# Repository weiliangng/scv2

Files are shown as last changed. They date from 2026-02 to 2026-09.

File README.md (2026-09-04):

# Technical documentation

- [SCV2 website source](website/README.md)
- [USB CLI setup and usage guide](CLI_GUIDE.md)
- [Downstream CAN telemetry receiver guide](CAN_TELEMETRY.md)
- [SCV2 technical documentation](https://merciful-iguanodon-c69.notion.site/RM8708A-Supercapacitor-controller-307fa7e594d880509271ff5a7605a5f0)

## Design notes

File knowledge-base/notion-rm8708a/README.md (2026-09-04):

# RM8708A Notion archive

This directory is a local, sanitized snapshot of the public Notion page
[`RM8708A Supercapacitor controller`](https://merciful-iguanodon-c69.notion.site/RM8708A-Supercapacitor-controller-307fa7e594d880509271ff5a7605a5f0).

- [`page.md`](page.md) preserves the page content in reading order.
- [`manifest.json`](manifest.json) records source identifiers, file sizes, and SHA-256 checksums.
- [`assets/`](assets/) contains the six embedded images, the social preview, the published firmware attachment, and two externally embedded TI PDFs.

The snapshot was captured from the anonymously accessible public-page API on
2026-09-04. Temporary Notion signed URLs, workspace permissions, user IDs, and
other unrelated internal metadata are intentionally not retained.

The page also links to project files that already live at the repository root:

- [`3D_4loko_2026-02-15.step`](../../3D_4loko_2026-02-15.step)
- [`ProPrj_supercap v0.1_2026-02-15.epro`](../../ProPrj_supercap%20v0.1_2026-02-15.epro)
- [`Calibration Script.ipynb`](../../Calibration%20Script.ipynb)

`assets/test.elf` is an untrusted binary snapshot. It has been archived but was
not executed.

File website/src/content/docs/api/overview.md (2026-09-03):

---
title: Interfaces overview
description: Choose and configure the referee UART, CAN, telemetry UART, and USB interfaces.
sidebar:
  order: 1
---

SCV2 separates robot control, fast telemetry, and bench diagnostics across four interfaces.

## Connections

| Interface | Configuration | Direction | Primary use |
|---|---|---|---|
| Referee UART | USART3, 115200, 8-N-1 | Receive | Referee power limit and buffer energy |
| CAN | Classic CAN, 1 Mbit/s | Bidirectional | Robot commands and fast telemetry |
| Telemetry UART | USART1 TX on PA9, 921600, 8-N-1 | Transmit | `T1` CSV record approximately every 10 ms |
| USB | CDC virtual COM port | Bidirectional | Interactive CLI and optional `T1` telemetry mirror |

## External control-source selection

External mode resolves the active command source in this order:

1. A fresh referee UART command
2. A fresh CAN command
3. No-source state when neither input is fresh

Command acceptance does not override protection. Faults, undervoltage lockout, capacitor-voltage lockout, direction rules, and switching timers may keep the power stage disabled.

## Choose an interface

### Robot integration

Use **CAN** for robot commands and the 1 kHz fast telemetry frame. Use **referee UART** when SCV2 should receive referee power and energy directly.

### Continuous diagnostics

Use **USART1 telemetry** for an always-on 69-field `T1` stream without sharing the USB port. Connect a 3.3 V receiver to PA9 at 921600 baud.

### Bench and pit work

Use **USB CDC** for the interactive CLI. USB can also mirror `T1` telemetry, but only one host application can normally own the COM port at a time.

## Next steps

- Decode the fast frame: [CAN telemetry](../can-telemetry/)
- Operate the diagnostic console: [USB CLI](../usb-cli/)
- Connect the dashboard: [Telemetry transports](../telemetry/)

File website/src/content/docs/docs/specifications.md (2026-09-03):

---
title: Technical specifications
description: Electrical limits, control modes, performance, and protection behavior.
sidebar:
  order: 1
---

## Electrical limits

| Port | Parameter | Range or limit |
|---|---|---|
| **IN — chassis bus** | Voltage | 12–28 V |
| | Current limit | −10 to +10 A; programmable in debug mode |
| | Power setting | −240 to +240 W in 1 W steps |
| | Reverse-flow voltage limit | 26.2 V if the battery disconnects or shuts down while reverse power is set |
| **OUT — supercapacitor** | Voltage and setting | 5–30 V; digitally programmable |
| | Current limit | −15 to +15 A; fixed limits |
| **Response** | Chassis load-step settling | <1 ms; 150 μs typical |
| **Performance** | Peak efficiency | Up to 97% |
| **Energy** | Supported bank | Up to 2,000 J stored |
| | Expected usable energy | Approximately 1,200–1,400 J |

## Sign convention

- **Positive power** flows from IN to OUT and charges the supercapacitor bank.
- **Negative power** flows from OUT to IN and supports the chassis bus.

The current and power limits apply to magnitude and direction. Read negative telemetry values using this convention rather than treating them as faults.

## Regulation

SCV2 supports:

- Constant input-power regulation
- Constant-current / constant-voltage charging
- Digitally programmable capacitor voltage
- External control using referee UART or CAN
- Manual and measurement modes for commissioning
- Guarded direct mode for expert bench work

## Protection and fault handling

The hardware provides:

- Short-circuit current limiting
- Overvoltage detection and shutdown on both ports
- IN-port undervoltage lockout
- Latched overvoltage status reporting
- Capacitor degradation detection
- Charge-voltage foldback when added energy does not produce the expected voltage rise
- Prevention of unintended backfeeding or “zombie power”

:::caution
The hardware is designed to tolerate hot-plugging the source and a charged or discharged capacitor bank, but these are not recommended operating procedures.
:::

## Related reference

- [Operating envelope](../operating-envelope/)
- [Interfaces overview](../../api/overview/)
- [CAN telemetry status bits](../../api/can-telemetry/#status-byte)

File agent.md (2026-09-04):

# SCV2 USB CLI, control, and telemetry guide

This document is the operating reference for agents and bench users working with the SCV2 firmware. The command implementation in `Core/Src/usb_cli.c`, the resolver in `Core/Src/scap_io_owner.c`, and constants in `Core/Inc/app_constants.h` are the source of truth. Check those files before extending this guide or relying on a remembered behavior.

## Agent operating rules

- Start with read-only observation: connect the USB CDC port, run `help`, disable the USB telemetry mirror if it obscures the prompt, and run `status`.
- Infer command effects by tracing the CLI handler through its mailbox or HAL call and then through `ScapIo_Resolve1kHz()` and the ADC ISR. An `ok` response only means the command was accepted; verify the requested state with `status` or `T1`, and verify the physical result with `swen_out`, GPIO measurement, or appropriate bench equipment.
- Do not guess the COM port, safe supply/load conditions, calibration values, GPIO target, DAC value, or acceptable power setpoint. If the requested hardware operation or its safe value is not explicit and cannot be established from the repository and fixture description, ask the user before issuing a mutating command.
- Treat `ctrl direct`, `gpio`, `dac`, `cal set`, `cal load`, and `cal save` as hardware-mutating operations. Use a current-limited, known-safe bench setup and arrange a shutdown path before using them.
- When this document and firmware disagree, document the observed mismatch and follow the current source. Do not silently preserve an obsolete test expectation.

## USB CLI quick start

The CLI is exposed as the board's USB CDC virtual COM port. Repository tooling conventionally opens it at 115200 baud, 8-N-1; USB CDC does not use that setting as a physical UART baud rate. The separate USART1 telemetry output is 921600 baud, 8-N-1 and is not the CLI.

1. Connect the board's USB device port and identify its virtual COM port. Do not assume the example `COM8` is correct for the current host.
2. Open the port in a serial terminal. Either CR or LF submits a command.
3. Wait for `CLI ready. Type 'help'.` and the `scv2> ` prompt. Press Enter once if the board was already running before the terminal connected.
4. Run `telemetry off` for a clean interactive prompt, then run `help` and `status`.

`status` deliberately averages 1000 samples with a 1 ms delay, so expect it to take about one second. It does not write control state, but command freshness and physical conditions can change while it is sampling. `telemetry on` interleaves `T1` records with ordinary CLI output on the same USB stream; the USART1 `T1` stream remains on regardless of this setting.

## CLI command reference

| Command | What it does | Important constraints |
|---|---|---|
| `help` | Prints the supported command syntax. | `dir` and `mode` are dispatched but intentionally absent because they are unavailable. |
| `status` | Reports control decision, physical pins, safety state, averaged electrical values, command mailboxes, telemetry/link statistics, DAC values, and ISR timing. | Read-only, but takes about one second. The displayed "Current mode" is the resolver decision, not merely the requested `ctrl` mode. |
| `telemetry on\|off\|toggle` | Controls the lossy USB mirror of `T1`. | Does not change the always-on USART1 stream or control behavior. |
| `ctrl external` | Selects external control. | Fresh UART power **and** energy win over fresh CAN; otherwise fresh CAN is used; otherwise the decision is `no-source`. |
| `ctrl manual` | Selects manual algorithm control. | Uses the last `pset`, or 50 W if none has been published. Manual SWEN is selected by timestamp against the pushbutton mailbox. |
| `ctrl measure` | Selects measurement mode. | Forces the requested SWEN output off without waiting for the minimum-on timer. |
| `ctrl direct` | Relinquishes normal MODE, DIR, SWEN, LED, and DAC1 algorithm updates so they can be driven directly. | Fault/watchdog and UVLO handling still take priority. Enter only on a safe bench. |
| `pset <-240..240>` | Publishes a persistent manual power mailbox in watts. | It affects power only in manual mode; it does not switch modes or enable SWEN. |
| `swen <0\|1>` | Publishes a persistent manual SWEN mailbox. | It affects output selection only in manual mode. The newer pushbutton/manual mailbox wins, and safety still overrides it. |
| `gpio write <PIN> <0\|1>` | Writes a GPIO output. | The parser accepts optional `P`, ports compiled for the MCU, and pins `0..15`, case-insensitively; it is not an allowlist of safe outputs. |
| `gpio toggle <PIN>` | Toggles a GPIO output. | Same parser and hazards as `gpio write`. |
| `dac set <1\|3> <1\|2> <0..4095>` | Writes a raw 12-bit DAC value. | DAC1 requires `ctrl direct`; DAC3 does not. Values are volatile unless represented by saved boot calibration. |
| `cal set <NAME> <VALUE>` | Changes an active calibration constant in RAM. | Does not persist until `cal save`; the two DAC3 boot values are also applied to hardware immediately. |
| `cal load` | Loads the saved calibration set from emulated EEPROM and applies the saved DAC3 boot values. | Returns an error if no valid saved set exists and replaces unsaved RAM changes. |
| `cal save` | Saves the complete active calibration set to emulated EEPROM. | Persistent hardware mutation; verify values before saving. |
| `dir ...` / `mode ...` | Returns `unavailable: main mode control is staged off`. | Use guarded GPIO commands in direct mode instead. |

Power-stage GPIO writes and toggles for PB1/DIR, PB4/SWEN, PB5/MODEMSB, PB6/MODELSB, and PA10/LED are rejected unless the requested mode is direct. Other syntactically valid pins are not protected by this check; writing a peripheral-owned, input-only, or otherwise unsafe pin can still disrupt the board.

Calibration names are `A_VBUS`, `B_VBUS`, `A_ILOAD`, `B_ILOAD`, `MIDPOINT`, `A_INP`, `B_INP`, `A_INN`, `B_INN`, `A_VCAP`, `B_VCAP`, `A_OP`, `B_OP`, `A_ON`, `B_ON`, `DAC3_CH1_BOOT_U12`, and `DAC3_CH2_BOOT_U12`. Float inputs must be finite; `A_VBUS` must also be nonzero, and DAC boot values must be `0..4095`.

## Safe command workflows

### Observe without changing control

```text
telemetry off
status
```

Use `telemetry on` only when a consumer is ready to separate complete `T1` lines from the prompt and command responses.

### Manual power and SWEN

```text
swen 0
pset 80
ctrl manual
status
swen 1
status
swen 0
ctrl external
status
```

Set `swen 0` and confirm the physical SWEN pin before enabling the power stage. The `pset` and manual `swen` mailboxes persist until reset or replacement. A mode or resolver-decision transition publishes pushbutton SWEN off; after entering manual mode, the newest manual `swen` or physical pushbutton event determines the request.

### Direct GPIO or DAC1 work

```text
ctrl direct
gpio write PB4 0
# perform only the explicitly planned GPIO/DAC operations
gpio write PB4 0
ctrl external
status
```

Direct mode leaves the current stage outputs in their applied state; entering it does not automatically clear every pin. Before leaving, explicitly put altered outputs into the intended safe state. Fault/watchdog handling can still force SWEN off, and UVLO can still update DIR/DAC1 while holding SWEN off.

### Calibration

At the start of a calibration session, before making unsaved changes, record `status` and the values printed by a successful `cal load`. Use `cal set` for one value at a time, validate the measurements, and run `cal save` only after the complete active set is known-good. There is no read-only CLI command that prints the active calibration set: `cal load` replaces RAM values and applies the saved DAC3 boot outputs, so never use it merely to inspect values that must not be changed.

## Control behavior inferred from `scap_io_owner.c`

The 1 kHz resolver publishes a double-buffered fast command, and the ADC ISR applies the physical DIR, DAC1, SWEN, and LED behavior. The priority and source flow are:

1. A watchdog failure or latched Vbus/Vcap over-voltage fault forces SWEN off immediately. A fault clears only after 500 consecutive safe 1 kHz resolver cycles and a subsequent fault-free fast update.
2. Vbus UVLO enters at `<=10 V`, exits at `>=11 V`, and forces SWEN off.
3. Direct mode leaves normal power-stage output ownership to direct writes; measure mode forces SWEN off; manual mode uses manual inputs; external mode selects fresh UART power+energy before fresh CAN.
4. CAN and UART fields are fresh for 300 ms. No fresh external source produces `no-source`, zero power, and a false SWEN policy request.
5. Outside direct, measure, fault, and UVLO handling, SWEN observes a 50 ms minimum-on time and a 1 ms minimum-off time.

For enabled external commands with valid energy, SWEN permission is based on converter direction and Vcap lockout, not on crossing an energy threshold. The initial runtime maximum is 26.3 V. Charging is allowed only while `i_conv > 0` and Vcap is below that maximum; it resumes at 0.1 V below the current maximum. The discharge lockout is 20% of the current maximum and resumes 0.1 V above that level. Initially these thresholds are 26.3/26.2 V for charge and 5.26/5.36 V for discharge. A zero converter-current command allows neither direction.

Energy changes the resolved power setpoint while a direction is allowed:

| Direction | Energy condition | Resolved power adjustment |
|---|---|---:|
| Charge | `energy > 50 J` | `command power + 10 W` |
| Charge | `energy <= 50 J` | `command power - 20 W` |
| Discharge | `energy < 20 J` | `command power - 10 W` |
| Discharge | `energy >= 20 J` | `command power + 20 W` |

CAN energy `777` is the disabled sentinel: it bypasses both the direction/Vcap energy-policy permission and the power adjustment, but it does not bypass command freshness, the CAN SWEN bit, fault/watchdog handling, UVLO, or minimum-on/off timing.

Outside direct mode the resolver writes MODE[1:0] to `01`, the normal algorithm mode. Use `swen_req` to see the selected source's request, `decision` to see which control branch won, `pset_W` to see the adjusted power, and `swen_out` to verify what the hardware actually received.

## Telemetry `T1` decoder

USART1 emits one CSV record every 10 ms from boot at 921600 baud, 8-N-1. The USB CLI command `telemetry on|off|toggle` controls an independent USB CDC mirror of the same records; it does not affect USART1 or control. Every record starts with `T1`; remaining columns are positional and must be decoded in the order below. It is a best-effort snapshot, so DMA, register, and shared-state values can be up to one control cycle apart.

### Conventions

- **Binary** is `0` or `1`.
- **Continuous** is a decimal integer in the stated unit.
- **N-ary** is a decimal enum defined below.
- Raw ADC and DAC values are unsigned 12-bit counts (`0..4095`).
- `valid` means a mailbox has published an accepted value. `fresh` means it is within the shared 300 ms command timeout for CAN and UART.

### Columns

| # | Field | Type / range | Meaning and source |
|---:|---|---|---|
| 1 | `seq` | continuous, uint32 | T1 telemetry record sequence shared by USART1 and USB. |
| 2 | `adc_hz` | continuous, Hz | Measured ADC1 DMA sequence rate. |
| 3 | `usb_drop` | continuous, uint32 | Cumulative records rejected by the lossy USB telemetry queue. |
| 4 | `dma_last` | continuous, cycles | Last ADC1 DMA ISR execution time. |
| 5 | `dma_max` | continuous, cycles | Maximum ADC1 DMA ISR execution time since boot. |
| 6 | `adc_vcap` | continuous, 0..4095 | ADC1 rank 1 raw Vcap input: PA0 / ADC1_IN1. |
| 7 | `adc_vbus` | continuous, 0..4095 | ADC1 rank 2 raw Vbus input: PA1 / ADC1_IN2. |
| 8 | `adc_iload` | continuous, 0..4095 | ADC2 rank 1 differential Iload sample: PA6/PA7. |
| 9 | `adc_iop` | continuous, 0..4095 | ADC2 rank 2 IMONOP sample via OPAMP2: PB14. |
| 10 | `adc_ion` | continuous, 0..4095 | ADC2 rank 3 IMONON sample via OPAMP3: PB13. |
| 11 | `vc_mV` | continuous, signed mV | `adc_vcap` after active Vcap calibration. |
| 12 | `vb_mV` | continuous, signed mV | `adc_vbus` after active Vbus calibration. |
| 13 | `il_mA` | continuous, signed mA | `adc_iload` after active Iload calibration. |
| 14 | `iop_mA` | continuous, signed mA | `adc_iop` after active IMONOP calibration. |
| 15 | `ion_mA` | continuous, signed mA | `adc_ion` after active IMONON calibration. |
| 16 | `io_mA` | continuous, signed mA | Selected output current: larger of IMONOP and negative IMONON. |
| 17 | `ic_mA` | continuous, signed mA | Calculated converter-current command, clamped to ±10 A. |
| 18 | `pset_W` | continuous, signed W | Power setpoint selected by the control resolver. |
| 19 | `btn_in` | binary | Physical PC13 pushbutton level; control uses its debounced rising edge. |
| 20 | `dir_out` | binary | Physical PB1 direction output; `1` is positive converter-current direction. |
| 21 | `swen_out` | binary | Physical PB4 switch-enable after safety, direction/Vcap policy, and min-on/off gating. |
| 22 | `mode_out` | n-ary, 0..3 | Physical PB5:PB6 mode bits (`2*MODEMSB + MODELSB`); normal algorithm mode is `1`. |
| 23 | `rvsoff_out` | binary | Physical PB3 reverse-switch-off output. |
| 24 | `nsil_out` | binary | Physical PB7 NSIL output. |
| 25 | `led_out` | binary | Physical PA10 status LED output. |
| 26 | `dac1_ch1` | continuous, 0..4095 | Live DAC1 channel 1, IMONINP comparator/reference output. |
| 27 | `dac1_ch2` | continuous, 0..4095 | Live DAC1 channel 2, IMONINN comparator/reference output. |
| 28 | `dac3_ch1` | continuous, 0..4095 | Live DAC3 channel 1, OPAMP1 feedback/reference output. |
| 29 | `dac3_ch2` | continuous, 0..4095 | Live DAC3 channel 2, COMP4 reference output. |
| 30 | `mode_req` | n-ary, 0..3 | Requested mode: `0=external`, `1=manual`, `2=measure`, `3=direct GPIO`. |
| 31 | `decision` | n-ary, 0..7 | Resolver result: `0=fault disable`, `1=idle/UVLO`, `2=no source`, `3=manual algorithm`, `4=CAN algorithm`, `5=UART algorithm`, `6=measure`, `7=direct GPIO`. |
| 32 | `swen_req` | binary | Resolver request before final output gating. |
| 33 | `safe` | binary | Current ADC safety check has no Vbus/Vcap over-voltage fault. |
| 34 | `uvlo` | binary | Undervoltage lockout; enters at Vbus ≤10 V, exits at Vbus ≥11 V. |
| 35 | `fault_latched` | binary | Over-voltage fault is latched and forces SWEN off until recovery. |
| 36 | `fault_bits` | bitmask, 0..3 | `bit0=Vbus ≥30 V`; `bit1=Vcap ≥30 V`. |
| 37 | `fault_healthy_ms` | continuous, 0..500 | Consecutive safe time while clearing a latched fault. |
| 38 | `can_bus` | binary | Any CAN FIFO1 traffic observed in the last 200 ms. |
| 39 | `can_p` | continuous, W 50..120 when valid | CAN command power. |
| 40 | `can_p_valid` | binary | Valid CAN command packet accepted since boot. |
| 41 | `can_p_fresh` | binary | CAN command is no more than 300 ms old. |
| 42 | `can_e` | continuous, J 0..60 or 777 | CAN energy used for power adjustment; `777` disables the energy/Vcap policy. |
| 43 | `can_e_valid` | binary | Accepted CAN energy is usable: packet valid and `can_e != 777`. |
| 44 | `can_e_fresh` | binary | CAN energy packet freshness, shared with CAN power. |
| 45 | `can_e_disabled` | binary | CAN energy is the `777` disabled sentinel. |
| 46 | `can_swen` | binary | SWEN request carried by the CAN packet. |
| 47 | `can_swen_valid` | binary | Valid CAN command packet accepted since boot. |
| 48 | `can_swen_fresh` | binary | CAN SWEN packet freshness, shared with CAN power. |
| 49 | `uart_p` | continuous, W 50..120 when valid | Referee UART chassis power limit. |
| 50 | `uart_p_valid` | binary | CRC-validated referee power frame parsed since boot. |
| 51 | `uart_p_fresh` | binary | UART power is no more than 300 ms old. |
| 52 | `uart_e` | continuous, J 0..60 when valid | Referee UART buffer energy. |
| 53 | `uart_e_valid` | binary | CRC-validated referee energy frame parsed since boot. |
| 54 | `uart_e_fresh` | binary | UART energy is no more than 300 ms old. |
| 55 | `uart_swen_req` | binary | Derived request: `1` only while UART power and energy are both fresh. |
| 56 | `man_p` | continuous, signed W -240..240 when valid | Manual CLI power mailbox; it does not expire. |
| 57 | `man_p_valid` | binary | Manual power has been set by the CLI since boot. |
| 58 | `man_swen` | binary | Manual CLI SWEN mailbox request; it does not expire. |
| 59 | `man_swen_valid` | binary | Manual SWEN has been set by the CLI since boot. |
| 60 | `btn_swen` | binary | Debounced pushbutton SWEN mailbox request; it does not expire. |
| 61 | `btn_swen_valid` | binary | Pushbutton SWEN mailbox set since boot or reset by a mode transition. |
| 62 | `cap_energy_mJ` | continuous, signed mJ | Integrated capacitor energy; charging adds and discharging subtracts. |
| 63 | `vcap_max_mV` | continuous, mV | Current runtime Vcap maximum used by charge lockout, discharge lockout, and CAN capacity scaling. |
| 64 | `cap_unhealthy` | binary | Latched once three consecutive bad one-minute capacitor-health windows cause a derate. |
| 65 | `cap_bad_windows` | continuous, 0..3 | Current consecutive bad-window count; reset after a derate or a good window. |
| 66 | `cap_derates` | continuous, uint8 | Number of 0.1 V runtime derates since boot. |
| 67 | `cap_dE_mJ_min` | continuous, signed mJ/min | Integrated energy change measured over the last completed one-minute health window. |
| 68 | `cap_dV_mV_min` | continuous, signed mV/min | Vcap trend from averaged endpoints of the last completed one-minute health window. |
| 69 | `can_tx_enqueue_fail` | continuous, uint32 | Cumulative `HAL_FDCAN_AddMessageToTxFifoQ()` failures since boot; this does not report missing acknowledgements or arbitration delays. |

`cap_energy_mJ` starts at zero. The 50 kHz ADC ISR integrates signed `Vcap * Iout` energy into 50-sample (1 ms) blocks; the 1 kHz task transfers completed blocks into the signed run-long counter while retaining fractional mJ. `Iout` is forced to zero while SWEN is off. On each upward crossing of 23.0 V the counter is rebased to 1,322,500 mJ, the ideal stored energy of a 5 F capacitor at 23.0 V. The anchor re-arms after Vcap falls to 22.9 V or below.

The capacitor-health check compares energy and voltage across non-overlapping one-minute windows. Its voltage trend compares the average Vcap from the first 10 seconds with the average from the last 10 seconds, normalized to mV/min; raw Vcap remains in use for the 23 V anchor and control thresholds. A window is bad when energy rises by at least 500,000 mJ while the averaged Vcap trend is less than 100 mV/min. Three consecutive bad windows latch `cap_unhealthy`, reduce the runtime Vcap maximum by 0.1 V, and restart the count. Repeated groups of three bad windows continue derating down to a 23.0 V floor. The maximum, latch, and counters reset on reboot; the fixed 30 V hardware-safety threshold is unchanged.

### Control precedence

In external mode, fresh UART power plus energy wins; otherwise fresh CAN is used; otherwise the controller has no source. In manual mode, the newer pushbutton or manual-SWEN mailbox wins. Faults and UVLO override normal operation. Valid external energy adjusts `pset_W`; converter direction and Vcap lockout determine whether that source may enable SWEN. Use `swen_out` to verify what hardware actually received.

### External dashboard

The dashboard is maintained and released independently in
[`weiliangng/scv2-dashboard`](https://github.com/weiliangng/scv2-dashboard).
That repository owns the desktop source, dependencies, Windows packaging,
usage documentation, CI, and dashboard releases. This firmware repository owns
the `T1` producer and its field semantics; coordinate changes to the number,
order, units, or meaning of `T1` fields with the dashboard repository.

The firmware provides an optional USB CDC `T1` mirror controlled by the
`telemetry on`, `telemetry off`, and `telemetry toggle` CLI commands. It also
provides the always-on USART1 TX telemetry stream at 921600 baud. Dashboard
connection handling and bridge network configuration are documented in their
respective repositories. CLI commands can mutate hardware, so use the same
safe-bench constraints as a serial terminal.

### Firmware releases

To publish firmware, push an annotated tag matching `firmware-v*`, for example
`firmware-v1.0.0`. `.github/workflows/firmware-release.yml` builds MinSizeRel
firmware on Linux with pinned Arm GNU Toolchain 14.3.Rel1 and publishes only
`SCV2_Firmware.elf`, `.bin`, `.hex`, `.map`, build metadata, and firmware
checksums. `SCV2_Firmware.elf` is the file for STM32CubeProgrammer.

To verify that a release ELF matches a local build, run:

```powershell
Get-FileHash -LiteralPath .\build\MinSizeRel\test.elf -Algorithm SHA256
```

Compare it with `SCV2_Firmware.sha256` from the release. Equal SHA-256 values
mean the two ELF files are byte-for-byte identical. The release's
`SCV2_Firmware.build.txt` records the compiler and build-tool versions to
diagnose a mismatch.

## CAN five-byte command test guide

This is an automation-ready bench-test matrix for commands sent by the DEVC/peer device to this board. It covers protocol and control-behaviour equivalence classes and validation boundaries; it is intentionally not a brute-force test of all `2^40` possible payloads.

### Test-rig correlation and safe profiles

- The sender STM32 writes `CASE <id>` to its USB CDC port immediately before it transmits the listed CAN frame. The host records that event and SCV2's `T1` stream with one monotonic PC clock; it never tries to correlate by the ignored `reset` byte.
- Enable `telemetry on` on SCV2. A normal target observation is the first complete `T1` record after a case event, within 30 ms. FIFO1-only traffic is polled at 100 ms, so its `can_bus=1` observation has a 130 ms deadline. `T1` itself is sampled every 10 ms.
- Profile `S` means `mode_req=0`, both UART freshness fields are `0`, `safe=1`, `uvlo=0`, `fault_latched=0`, and no earlier energy/Vcap lockout is retained. Use a current-limited supply and a safe load; start with `enable_module=0` cases.
- Baseline `B0` is the accepted frame `[00 00 55 0A 00]`: power 85 W, energy 10 J, SWEN off. For a rejection test, send B0, wait at least 310 ms, then send the candidate. Immediately before the candidate, the expected retained state is `can_p=85`, `can_p_valid=1`, `can_p_fresh=0`, `can_e=10`, `can_e_valid=1`, `can_e_fresh=0`, `can_e_disabled=0`, `can_swen=0`, `can_swen_valid=1`, `can_swen_fresh=0`, `can_bus=0`, `decision=2`, `pset_W=0`, `swen_req=0`, and `swen_out=0`.
- `valid` means a command was accepted since boot; it does **not** expire. All three CAN `fresh` fields use the same accepted-command timestamp and become `0` only after more than 300 ms without another accepted command.
- Do not assert exact `seq`, ADC/DAC counts, measured voltages/currents, `dir_out`, or `led_out` unless the fixture controls their inputs. `swen_out` is exact only when the stated analogue/safety profile and its 1 ms/50 ms timing history make it deterministic.

### Wire contract

Send a Classic CAN **standard data frame** with 11-bit ID `0x067` and DLC `5`.

| Byte | Name | Encoding | Accepted values | Effect |
|---:|---|---|---|---|
| 0 | `enable_module` | unsigned byte | `0` or `1` | Publishes CAN SWEN request: `0=off`, `1=on`. |
| 1 | `reset` | unsigned byte | any `0..255` | Currently ignored; it does not reset faults, timers, or the mailbox. |
| 2 | `pow_limit` | unsigned byte, W | `50..120` | Sets the CAN power setpoint. |
| 3 | `energy_buffer` LSB | unsigned byte | see below | Low byte of the little-endian energy value. |
| 4 | `energy_buffer` MSB | unsigned byte | see below | High byte of the little-endian energy value. |

`energy_buffer = byte[3] + 256 * byte[4]`. It is valid when `0..60 J`, or when it is exactly `777` (`0x0309`, bytes `09 03`). `777` is the disabled-energy sentinel: it bypasses direction/Vcap permission and power adjustment but does not bypass freshness, the CAN SWEN bit, UVLO, fault handling, or the SWEN timing limiter.

For sender notation below, payloads are hexadecimal bytes in the order on the wire: `[enable reset power energy_LSB energy_MSB]`.

For every accepted packet with values `(P,E,SW)`, the common `T1` assertion within 30 ms is: `can_bus=1`, `can_p=P`, `can_p_valid=1`, `can_p_fresh=1`, `can_e=E`, `can_e_fresh=1`, `can_e_disabled=(E==777)`, `can_e_valid=(E!=777)`, `can_swen=SW`, `can_swen_valid=1`, and `can_swen_fresh=1`. Under profile `S`, it additionally gives `mode_req=0`, `decision=4`, and `swen_req=SW`. `pset_W=P` when `SW=0`, when `E=777`, or while no direction is allowed; an enabled valid-energy command uses the direction-dependent adjustment table above. The per-case cells below state the remaining exact or conditional output assertions.

### Transport and frame-shape tests

| Case | Frame sent and precondition | Expected observed `T1` values |
|---|---|---|
| T1 baseline | `S`; standard data ID `0x067`, DLC 5, `[00 00 50 00 00]` | Common accepted assertion `(50,0,0)`; also `swen_out=0`. |
| T2 wrong standard ID | `B0`; standard data ID `0x066`, DLC 5, `[00 00 50 00 00]` | Within 130 ms, `can_bus=1`. All B0 mailbox values remain retained and stale: `can_p=85`, `can_e=10`, `can_swen=0`, all CAN `valid=1`, all CAN `fresh=0`; in `S`, `decision=2`, `pset_W=0`, `swen_req=0`, `swen_out=0`. |
| T3 extended ID | `B0`; extended data ID `0x67`, DLC 5, `[00 00 50 00 00]` | Same T1 assertion as T2. The global non-matching extended filter sends this to FIFO1, not the command callback. |
| T4 remote frame | `B0`; standard remote ID `0x067`, DLC 5 | Through 210 ms, `can_bus=0` and every B0 field remains unchanged/stale. Remote frames are rejected by the global filter, so they do not enter FIFO0/FIFO1. |
| T5 wrong DLC | `B0`; standard data ID `0x067`, DLC `0..4` or `6..8` | Within 30 ms, `can_bus=1`; every B0 mailbox field remains unchanged/stale. This proves activity is noted before the DLC-5 check, but timestamp publication is not performed. |
| T6 FIFO drain/order | `S`; enqueue in order valid `[00 00 50 00 00]`, invalid `[02 00 50 00 00]`, valid `[01 FF 78 09 03]` | Within 30 ms of the queue becoming non-empty, common accepted assertion `(120,777,1)`, `decision=4`, `pset_W=120`, `swen_req=1`. With the switch known off for at least 1 ms, `swen_out=1`; `reset=FF` causes no separate effect. |

### Payload validation matrix

Every rejected payload uses stale B0. Therefore `can_p=85`, `can_e=10`, `can_swen=0`, all CAN `valid=1`, all CAN `fresh=0`, `decision=2`, `pset_W=0`, `swen_req=0`, and `swen_out=0` must remain true; because the ID/type/DLC are correct, `can_bus=1` must appear within 30 ms. This both proves mailbox preservation and proves that the rejected frame did not refresh B0's timestamp.

| Case | Payload and precondition | Expected observed `T1` values |
|---|---|---|
| P1 enable off | `S`; `[00 00 50 00 00]` | Common accepted assertion `(80,0,0)`; exact `swen_out=0`. |
| P2 enable on | `S`; `[01 00 50 00 00]` | Common accepted assertion `(80,0,1)` and `swen_req=1`. With an allowed charge direction, `pset_W=60` and SWEN may turn on; with an allowed discharge direction, `pset_W=70` and SWEN may turn on. With zero current direction or the relevant Vcap lockout, `pset_W=80` and `swen_out=0`. |
| P3 invalid enable | stale `B0`; `[02 00 50 00 00]`, then `[FF 00 50 00 00]` | Rejected assertion above for both frames. Values `2..255` form one invalid class. |
| P4 ignored reset | `S`; `[00 00 50 00 00]`, `[00 01 50 00 00]`, `[00 FF 50 00 00]` | After each frame, common accepted assertion `(80,0,0)` and `swen_out=0`. No T1 field distinguishes the three reset-byte values; no fault, UVLO, timing, or mailbox reset occurs. |
| P5 power below range | stale `B0`; `[00 00 00 00 00]`, `[00 00 31 00 00]` | Rejected assertion above for `0 W` and `49 W`. |
| P6 power lower boundary | `S`; `[00 00 32 00 00]` | Common accepted assertion `(50,0,0)`; `decision=4`, `pset_W=50`, `swen_out=0`. |
| P7 representative power | `S`; `[00 00 55 00 00]` | Common accepted assertion `(85,0,0)`; `decision=4`, `pset_W=85`, `swen_out=0`. |
| P8 power upper boundary | `S`; `[00 00 78 00 00]` | Common accepted assertion `(120,0,0)`; `decision=4`, `pset_W=120`, `swen_out=0`. |
| P9 power above range | stale `B0`; `[00 00 79 00 00]`, `[00 00 FF 00 00]` | Rejected assertion above for `121 W` and `255 W`. |
| P10 energy lower boundary | `S`; `[00 00 50 00 00]` | Common accepted assertion `(80,0,0)`; `swen_out=0`. |
| P11 energy boundaries | `S`; `[00 00 50 14 00]`, `[00 00 50 37 00]`, `[00 00 50 3C 00]` | Respectively common accepted assertions `(80,20,0)`, `(80,55,0)`, `(80,60,0)`; each has `can_e_valid=1`, `can_e_disabled=0`, `swen_req=0`, `swen_out=0`. |
| P12 energy just above range | stale `B0`; `[00 00 50 3D 00]` | Rejected assertion above (`61 J`). |
| P13 energy-disabled sentinel | `S`; `[01 00 50 09 03]` | Exact accepted values: `can_p=80`, `can_e=777`, `can_e_valid=0`, `can_e_disabled=1`, `can_swen=1`, all CAN valid/fresh fields as defined above, `decision=4`, `pset_W=80`, `swen_req=1`. If SWEN has been off for at least 1 ms, `swen_out=1`. |
| P14 other high energy | stale `B0`; `[00 00 50 0A 03]`, `[00 00 50 FF FF]` | Rejected assertion above for `778 J` and `65535 J`. |
| P15 byte order | stale `B0`; `[00 00 50 03 09]` | Rejected assertion above: bytes decode little-endian as `0x0903=2307 J`, not 777 J. |

### End-to-end controller-effect tests

`decision=4` is only expected in external mode while both UART freshness fields are zero. `ScapIo_Resolve1kHz()` selects the source and applies the direction/Vcap permission, energy power adjustment, and SWEN timing, then the fast ADC ISR applies the published output request plus immediate safety overrides; allow two `T1` samples before treating an output as settled.

| Case | Preconditions and command | Expected observed `T1` values |
|---|---|---|
| C1 CAN selected | `S`; send valid `[00 00 55 0A 00]` every 50 ms | On every sample after the first: common accepted assertion `(85,10,0)`, `decision=4`, `pset_W=85`, `swen_req=0`, `swen_out=0`. There must be no sample with CAN freshness zero between refreshes. |
| C2 CAN timeout | `S`; send one `[01 00 50 09 03]`, then stop | Up to 300 ms: P13 assertion. After 310 ms: `can_p=80`, `can_e=777`, `can_swen=1`, CAN `valid=1`, all CAN `fresh=0`, `can_e_valid=0`, `can_e_disabled=1`, `decision=2`, `pset_W=0`, `swen_req=0`; `swen_out=0` after any outstanding 50 ms minimum-on interval. |
| C3 periodic refresh | `S`; send P13 at 50 ms intervals for 500 ms | Every post-settle T1 record has P13's exact mailbox fields, all CAN freshness fields `1`, `decision=4`, `pset_W=80`, `swen_req=1`, and (after the initial minimum-off interval) `swen_out=1`. |
| C4 UART precedence | Supply fresh valid UART power and energy; send P13 | CAN fields show P13 exactly, while `uart_p_fresh=1`, `uart_e_fresh=1`, `uart_swen_req=1`, and `decision=5`. `pset_W` uses UART power plus the applicable direction/energy adjustment, and `swen_req`/`swen_out` follow UART policy rather than CAN. After either UART freshness field reaches 0 while CAN remains fresh: `decision=4`, `pset_W=80`, `swen_req=1`. |
| C5 enable off | `S`; send `[00 00 50 09 03]` | Exact: `can_p=80`, `can_e=777`, `can_e_valid=0`, `can_e_disabled=1`, `can_swen=0`, all CAN valid/fresh fields `1`, `decision=4`, `pset_W=80`, `swen_req=0`, `swen_out=0`. |
| C6 sentinel enable on | `S`, switch off for at least 1 ms; send P13 | P13 exact assertion, including `swen_req=1`; `swen_out=1` in the next settled T1 record. |
| C7 charge adjustment | `S`; force `i_conv>0`, Vcap below the current runtime maximum, and no charge lockout. Send `[01 00 50 32 00]`, then `[01 00 50 33 00]` | At 50 J: common accepted `(80,50,1)`, `pset_W=60`, `swen_req=1`, and `swen_out=1` after the 1 ms off limit. At 51 J: common accepted `(80,51,1)`, `pset_W=90`, and SWEN remains requested/on. The energy boundary changes power, not enable permission. |
| C8 discharge adjustment | `S`; force `i_conv<0`, Vcap `>5.26 V`, and no discharge lockout. Send `[01 00 50 13 00]`, then `[01 00 50 14 00]` | At 19 J: common accepted `(80,19,1)`, `pset_W=70`, `swen_req=1`, and `swen_out=1` after minimum-off. At 20 J: common accepted `(80,20,1)`, `pset_W=100`, and SWEN remains requested/on. The energy boundary changes power, not enable permission. |
| C9 Vcap hysteresis | Charge profile: use 51 J, enter below the current runtime maximum, raise Vcap to that maximum, then lower it by 0.1 V. Discharge profile: use 19 J, enter above 20% of the current maximum, lower Vcap to that level, then raise it by 0.1 V. Initially these pairs are 26.3/26.2 V and 5.26/5.36 V. | In charge lockout, mailbox fields stay accepted/fresh, `decision=4`, `pset_W=80`, `swen_req=1`, and `swen_out=0`; after resume, `pset_W=90` and SWEN may turn on. In discharge lockout the corresponding values are `pset_W=80`/off, then `pset_W=70`/on after resume and timing. |
| C10 UVLO | `S`; keep P13 fresh, reduce Vbus to `<=10 V`, then restore to `>=11 V` | In UVLO: P13 mailbox fields remain fresh, `safe=1`, `uvlo=1`, `decision=1`, `pset_W=0`, `swen_req=0`, `swen_out=0`. After recovery and a fresh P13: `uvlo=0`, `decision=4`, `pset_W=80`, `swen_req=1`, `swen_out=1` after timing. |
| C11 over-voltage fault | `S`; keep P13 fresh, make Vbus or Vcap `>=30 V`, then restore both below 30 V for 500 ms | At fault: P13 mailbox fields may remain fresh, `safe=0`, `fault_latched=1`, `fault_bits=1` (Vbus), `2` (Vcap), or `3`, `decision=0`, `pset_W=0`, `swen_req=0`, `swen_out=0`. Reset-byte values do not change this. After safe time: `safe=1`, eventually `fault_latched=0`, `fault_bits=0`; with P13 still fresh, CAN resolution resumes. |
| C12 SWEN limits | `S`; keep P13 fresh. From a known off state send enable `1`, then send enable `0`, then `1` again | `swen_req` follows each accepted command within 30 ms. `swen_out` stays on for at least 50 ms after the on transition despite `swen_req=0`; after it goes off, it cannot turn on for at least 1 ms. T1's 10 ms period can show the 50 ms rule but cannot prove a 1 ms edge: use a GPIO logic analyser for that threshold. |

### Acceptance criteria

- Every accepted case has the published mailbox values stated in its row; a rejected case retains stale B0 and never refreshes its CAN freshness fields.
- `can_bus` is a separate 200 ms diagnostic timer. FIFO0 traffic sets it in the receive callback; non-matching data frames reach FIFO1 and set it only when the 100 ms task poll drains FIFO1; remote frames are hardware-rejected.
- The resolver and output chain is intentional: CAN packet validation publishes the mailbox, the 1 kHz resolver selects UART before CAN and then applies freshness, energy/Vcap policy, and SWEN timing; the ADC ISR applies that final output request and immediate safety overrides. A valid packet alone is never sufficient to require `swen_out=1`.

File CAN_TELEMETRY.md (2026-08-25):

# SCV2 CAN telemetry receiver guide

The SCV2 controller sends one Classic CAN data frame containing its fast electrical telemetry and fault status. The frame has eight payload bytes, but five logical items: three 16-bit measurements, one reserved byte, and one status byte.

## Frame contract

- Format: Classic CAN data frame (not CAN FD and not a remote frame)
- Identifier: standard 11-bit ID `0x077`
- DLC: 8 bytes
- Nominal bus rate: 1 Mbit/s
- Nominal update rate: 1 kHz
- Multi-byte order: little-endian (least-significant byte first)

The update rate is task-scheduled and best effort. A receiver must tolerate jitter and missing frames rather than assuming that a frame arrives at every exact millisecond.

| Byte(s) | Logical field | Raw type | Scale | Conversion |
|---|---|---|---|---|
| 0–1 | Load power | `uint16_t` | 0.1 W/count | `p_load_W = raw / 10.0` |
| 2–3 | Capacitor voltage | `uint16_t` | 0.1 V/count | `v_cap_V = raw / 10.0` |
| 4–5 | Converter-current command | signed 16-bit two's complement | 0.1 A/count | `i_conv_A = signed_raw / 10.0` |
| 6 | Reserved | `uint8_t` | — | Ignore; currently transmitted as zero |
| 7 | Status | `uint8_t` bitmask | — | Decode the status bits below |

The unsigned fields represent `0` through `6553.5` W/V. Negative load power or capacitor voltage is transmitted as zero, and larger values saturate at `6553.5`. Converter current represents `-3276.8` through `3276.7` A, although the current SCV2 control source clamps its command to ±10 A.

### Status byte

| Bit | Mask | Meaning when set |
|---:|---:|---|
| 0 | `0x01` | Vbus over-voltage fault latched |
| 1 | `0x02` | Vcap over-voltage fault latched |
| 2–7 | — | Reserved; ignore unknown bits |

The fault flags stay latched during the configured recovery interval. Downstream code should test masks rather than compare the complete status byte to a fixed value, so future status bits remain compatible.

## Portable C decoder

The example keeps the measurements in fixed-point deci-units. This avoids floating-point work in an interrupt and preserves the exact transmitted values. Convert to `float` later if the application needs engineering units.

```c
#include <stdbool.h>
#include <stddef.h>
#include <stdint.h>

enum
{
  SCV2_TELEMETRY_CAN_ID = 0x077u,
  SCV2_STATUS_VBUS_OVP = 1u << 0,
  SCV2_STATUS_VCAP_OVP = 1u << 1,
};

typedef struct
{
  uint16_t p_load_dW;  /* 0.1 W/count */
  uint16_t v_cap_dV;   /* 0.1 V/count */
  int32_t i_conv_dA;   /* 0.1 A/count; range is signed 16-bit */
  uint8_t status;
  bool vbus_ovp;
  bool vcap_ovp;
} scv2_telemetry_t;

static uint16_t read_u16_le(const uint8_t *bytes)
{
  return (uint16_t)bytes[0] | ((uint16_t)bytes[1] << 8);
}

static int32_t read_i16_le(const uint8_t *bytes)
{
  const uint16_t raw = read_u16_le(bytes);
  return ((raw & 0x8000u) != 0u) ? ((int32_t)raw - 65536L) : (int32_t)raw;
}

bool Scv2Telemetry_Decode(uint32_t identifier,
                          bool is_extended_id,
                          bool is_remote_frame,
                          uint8_t dlc_bytes,
                          const uint8_t *data,
                          scv2_telemetry_t *telemetry)
{
  if ((identifier != SCV2_TELEMETRY_CAN_ID) || is_extended_id ||
      is_remote_frame || (dlc_bytes != 8u) ||
      (data == NULL) || (telemetry == NULL))
  {
    return false;
  }

  telemetry->p_load_dW = read_u16_le(&data[0]);
  telemetry->v_cap_dV = read_u16_le(&data[2]);
  telemetry->i_conv_dA = read_i16_le(&data[4]);
  /* data[6] is reserved and deliberately ignored. */
  telemetry->status = data[7];
  telemetry->vbus_ovp = (data[7] & SCV2_STATUS_VBUS_OVP) != 0u;
  telemetry->vcap_ovp = (data[7] & SCV2_STATUS_VCAP_OVP) != 0u;
  return true;
}
```

After decoding, engineering-unit access is straightforward:

```c
const float p_load_w = (float)telemetry.p_load_dW * 0.1f;
const float v_cap_v = (float)telemetry.v_cap_dV * 0.1f;
const float i_conv_a = (float)telemetry.i_conv_dA * 0.1f;
```

Do not cast the eight-byte payload directly to a packed C struct. Explicit byte decoding works regardless of the downstream MCU's alignment rules and makes the wire endianness unambiguous.

## Worked frame

Given this payload:

```text
88 13 2C 01 9C FF 00 03
```

- Load power raw: `0x1388 = 5000`, therefore `500.0 W`
- Capacitor voltage raw: `0x012C = 300`, therefore `30.0 V`
- Converter current raw: `0xFF9C = -100`, therefore `-10.0 A`
- Reserved byte: `0x00`
- Status: `0x03`, so both Vbus and Vcap over-voltage flags are set

## Receiver integration guidance

1. Configure the downstream CAN peripheral for 1 Mbit/s Classic CAN and accept standard identifier `0x077` with DLC 8.
2. Reject extended, remote, and wrong-DLC frames before decoding.
3. In the receive ISR/callback, copy or decode the complete frame and record its arrival timestamp. Publish the result to task code using the downstream firmware's normal mailbox, critical-section, or double-buffer mechanism.
4. Keep the fixed-point values when possible; divide by ten only at display or control boundaries.
5. Ignore byte 6 and unrecognized status bits for forward compatibility.
6. Detect stale telemetry using the recorded arrival timestamp and a timeout selected for the downstream application's safety requirements. The SCV2 wire protocol does not impose a universal receiver timeout.

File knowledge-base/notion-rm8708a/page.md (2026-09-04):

---
title: RM8708A Supercapacitor controller
source: https://merciful-iguanodon-c69.notion.site/RM8708A-Supercapacitor-controller-307fa7e594d880509271ff5a7605a5f0
notion_page_id: 307fa7e5-94d8-8050-9271-ff5a7605a5f0
source_created_utc: 2026-02-14T17:32:57.590Z
source_last_edited_utc: 2026-03-30T19:05:27.142Z
captured: 2026-09-04
---

# RM8708A Supercapacitor controller

This is a Markdown snapshot of the public Notion page. The content has been
lightly normalized for readability, with embedded assets changed to stable
local paths.

## Pinout & Description

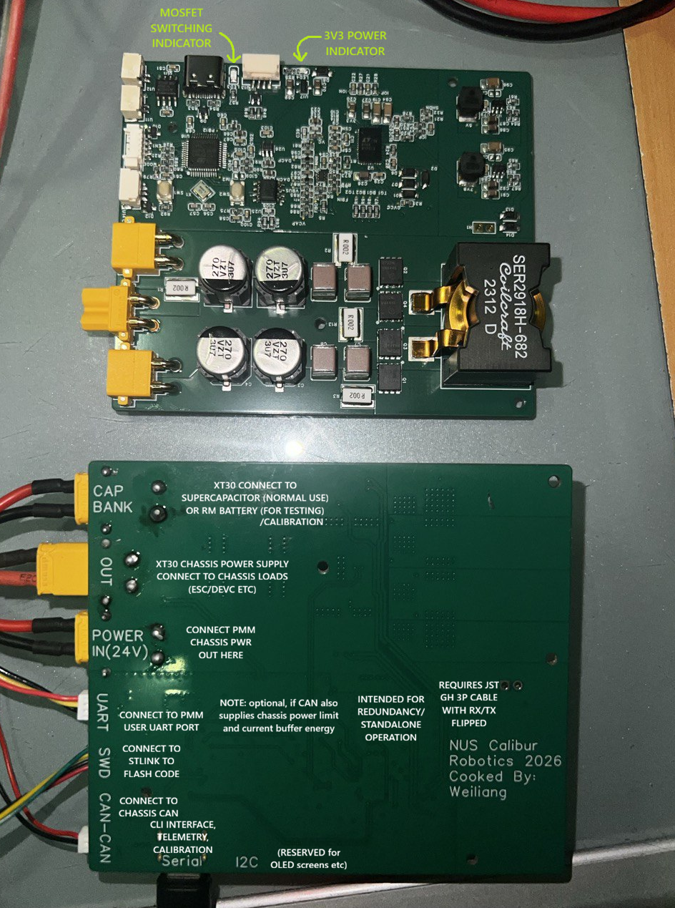
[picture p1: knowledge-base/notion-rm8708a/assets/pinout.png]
Annotated RM8708A controller pinout and connector photograph


## Example Wiring Diagram (Bare Minimum)

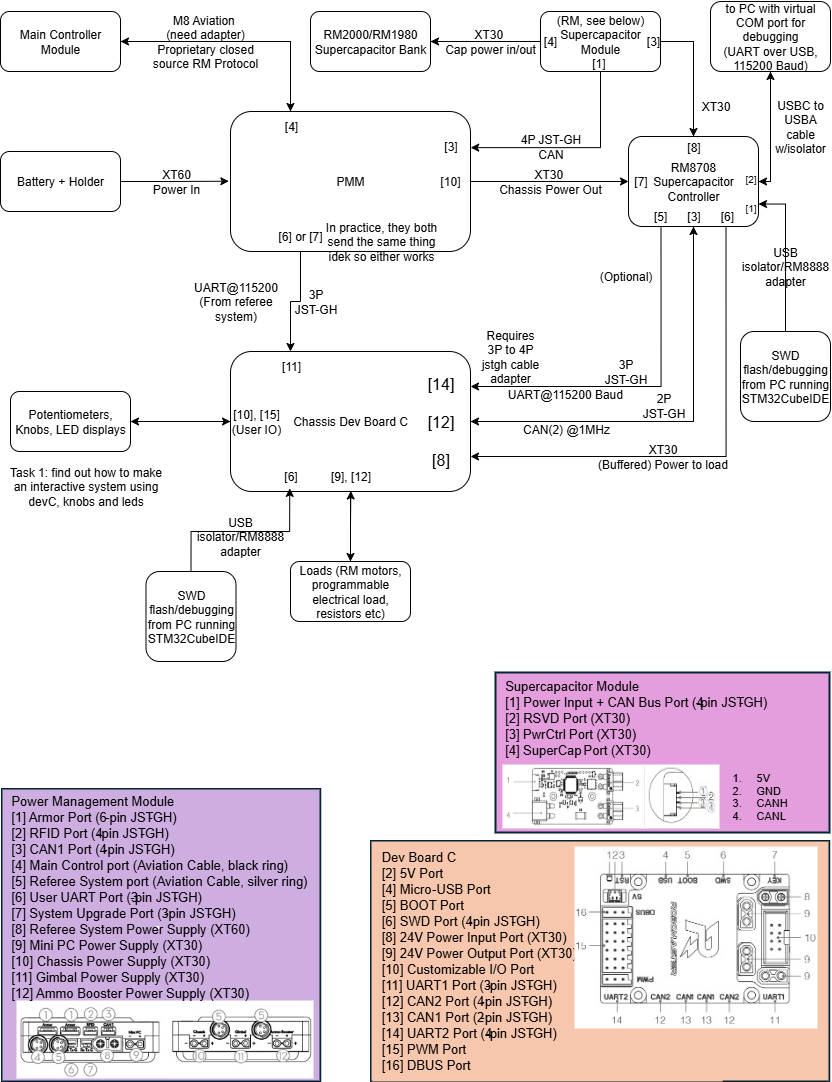
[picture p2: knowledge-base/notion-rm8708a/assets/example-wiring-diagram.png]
Bare-minimum RM8708A system wiring diagram


## Mechanical files

- [3D_4loko_2026-02-15.step](../../3D_4loko_2026-02-15.step)

Note that H1 is DNP, just a placeholder.

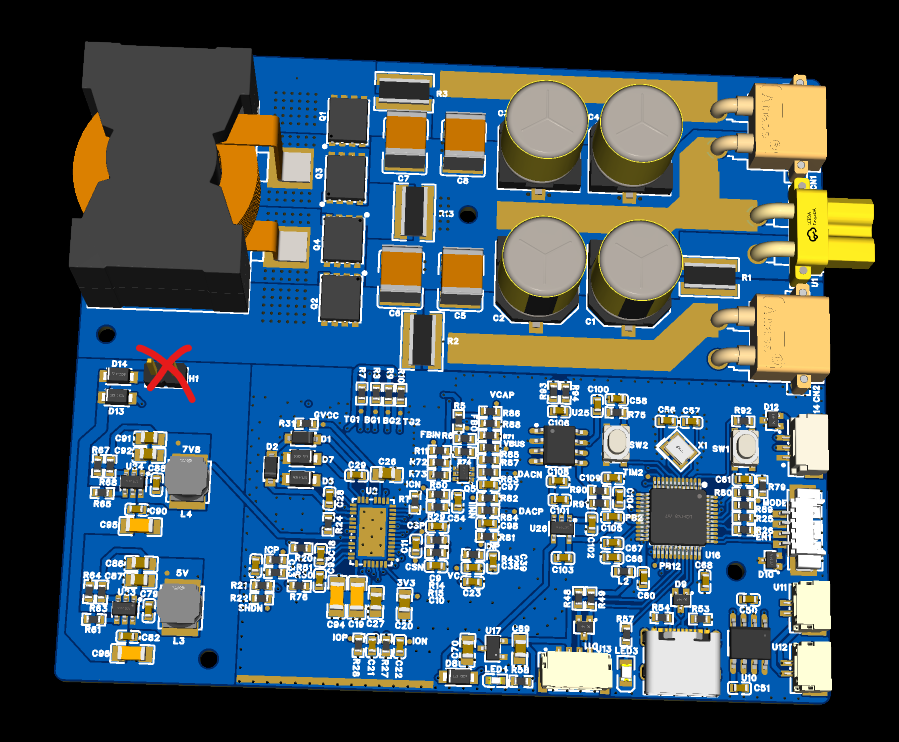
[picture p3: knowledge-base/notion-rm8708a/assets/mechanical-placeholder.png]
RM8708A populated-board 3D model with H1 marked DNP


## Hardware

- [EasyEDA Pro project: ProPrj_supercap v0.1_2026-02-15.epro](../../ProPrj_supercap%20v0.1_2026-02-15.epro)

NOTE: Download EasyEDA Pro to open, view and order.

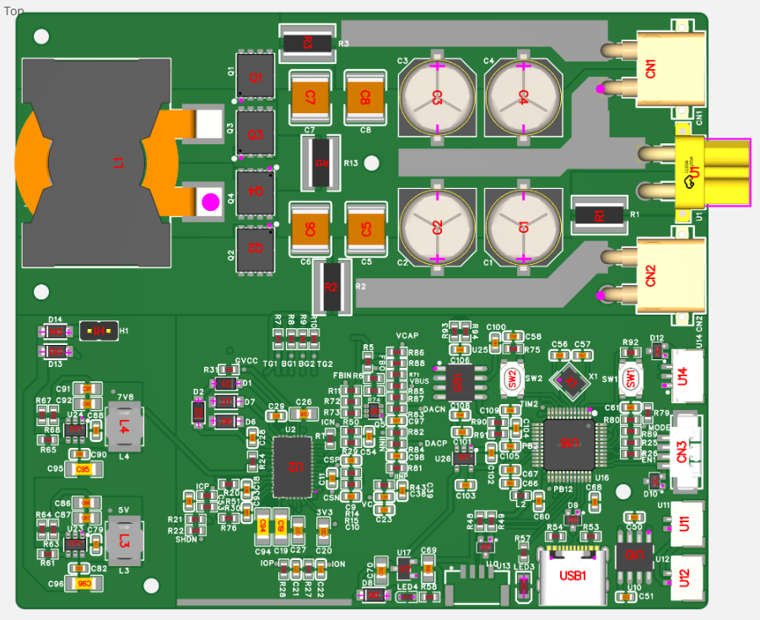
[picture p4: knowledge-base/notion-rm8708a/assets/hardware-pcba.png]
RM8708A PCBA rendering


Note: Project is PCBA ready, can be mass produced after testing is complete.

## Firmware

- [SCV2 GitHub repository](https://github.com/weiliangng/scv2)

Project has been configured for CLion; alternatively use CubeMX to generate
relevant config files for STM32CubeIDE.

Alternatively, directly flash the binary file using STM32CubeProgrammer (rename
to `.elf` extension) (untested).

- [Published firmware attachment](assets/test.elf)

## Programming

Before the flashed firmware will boot properly, you will need to program option
bytes using STM32CubeProgrammer. Use an ST-LINK with genuine STM32 chips (not
knockoffs; it is a gamble whether it works or not).

1. **Connect “Under reset” (not Hot plug).**
2. Set option bytes as follows (uncheck `nSWBOOT0`):

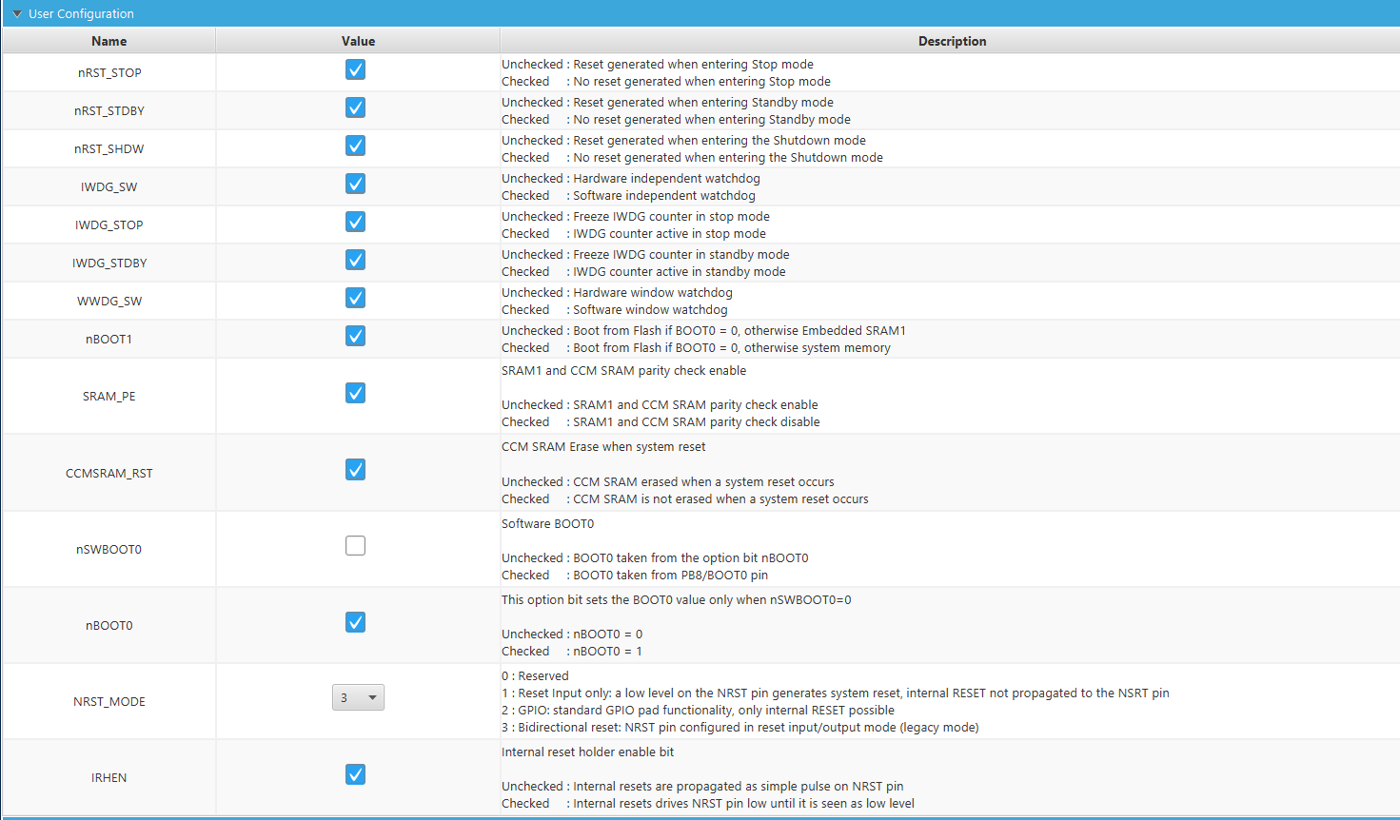
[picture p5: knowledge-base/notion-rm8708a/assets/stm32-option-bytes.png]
STM32CubeProgrammer option-byte configuration


## Calibration

- [Calibration Script.ipynb](../../Calibration%20Script.ipynb)

Fully automatic calibrator: currently only supports calibrating IIN-related
constants.

NOTE: Skip the PMM, skip the capacitor bank, use **two half-charged batteries**
(otherwise you will hit voltage limiting at higher currents).

NOTE: Requires Jupyter Notebook (Anaconda installation recommended for least
friction).

### Calibrating supercapacitor-side output voltage limit (manual)

NOTE: Requires the PuTTY serial terminal executable (or any equivalent serial
terminal; Python also works).

Connect via a COM port. Find it in Device Manager, or plug/unplug and use
elimination. Baud rate does not matter.

On boot, you will see telemetry spam. To shut it off, type `telemetry off`, then
type `help` for the list of commands.

DAC3 OUT1 sets the capacitor-side output voltage, just like the old version uses
a potentiometer.

The default value is 920 and should result in around 26.4–26.2 V output voltage
in real life, depending on component tolerances.

To tune it, increment or decrement values slightly and measure the output with
the grey DMM (not more than 100).

Expected behavior:

- Decreasing DAC output voltage should increase output voltage.
- Increasing DAC output voltage should decrease output voltage.

Do the following:

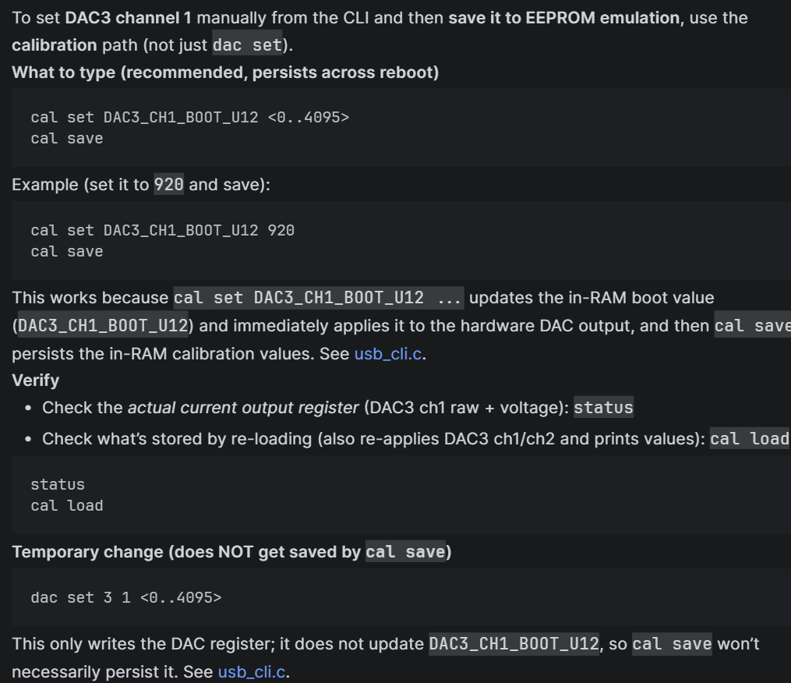
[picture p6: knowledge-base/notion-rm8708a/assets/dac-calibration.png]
DAC3 channel 1 calibration and persistence commands


## CAN API

Status packet:

```c
const uint32_t SCAP_STAT_ID = 0x077u; // SC status packets will have this ID; SC sends these packets

uint8_t data[8]; // Standard CAN packets: maximum 8 bytes

data[0] = (uint8_t)(v_bus_10mV & 0xFFu);
data[1] = (uint8_t)((v_bus_10mV >> 8) & 0xFFu); // Bus voltage in 10 mV increments
data[2] = (uint8_t)((uint16_t)i_load_10mA & 0xFFu);
data[3] = (uint8_t)(((uint16_t)i_load_10mA >> 8) & 0xFFu); // Chassis current in 10 mA increments
data[4] = (uint8_t)((uint16_t)i_conv_10mA & 0xFFu);
data[5] = (uint8_t)(((uint16_t)i_conv_10mA >> 8) & 0xFFu); // Target converter current in 10 mA increments
data[6] = capacity_pct; // Supercapacitor capacity percentage
data[7] = status_code;  // Reserved
```

Command packet:

```c
const uint32_t SCAP_CMD_ID = 0x067u; // SC command packets use this ID; SC listens to this ID
uint8_t data[8]; // Incoming packet

if (rxh.Identifier == SCAP_CMD_ID)
{
    const uint8_t settings = data[0]; // bit 0: enable or disable SWEN (other bits reserved)
    g_can_rx.can_power = (uint16_t)data[1] | ((uint16_t)data[2] << 8); // Alternate power limit if UART fails, in watts
    g_can_rx.can_buf = data[3]; // Alternate current-buffer energy if UART fails, in joules
```

The command snippet ends at that line on the source page.

## Pending tasks

- Check if six-layer performs significantly better than four-layer in terms of temperature and stability.
- Implement capacitor overcharge foldback protection in firmware.
- Implement Python calibration for other measurements (only IIN is calibrated for now).
- Test CAN functionality in the absence of UART.
- Test brownout option-byte functionality.
- Perform transient testing and compensation tuning in CV and CC modes.
- Reference: [TI SSZTCV2](assets/ti-ssztcv2.pdf).
- Finalize PCBA files and confirm parts availability (perform device standardization).
- Test with a real robot; wireless telemetry is highly recommended (ESP32).

## Extras

- Advanced: Draw up a game plan to measure and obtain Bode plots (may not be very feasible).
- [Dealing with high noise levels with a DIY injection transformer and PicoScope](https://www.eevblog.com/forum/projects/dealing-with-high-noise-levels-with-diy-injection-transformer-and-picoscope/)
- [DIY injection transformer for power-supply control-loop response measurements](https://www.eevblog.com/forum/projects/diy-injection-transformer-for-power-supply-control-loop-response-measurements/)
- Reference: [TI SNVA364A](assets/ti-snva364a.pdf).
- Advanced: Implement capacitance-measurement functionality.
- [How to measure very large capacitance](https://electronics.stackexchange.com/questions/387155/how-to-measure-very-large-capacitance-e-g-super-ultra-capacitors)

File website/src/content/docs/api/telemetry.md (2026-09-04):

---
title: Telemetry transports
description: Connect the SCV2 T1 telemetry stream over USB, external UART, or a UDP bridge.
sidebar:
  order: 4
---

SCV2 emits the current 69-field `T1` CSV telemetry record through USB CDC or
its dedicated telemetry UART. Desktop display and UDP bridge behavior are
owned by their separate repositories.

## Transport matrix

| Transport | Settings | Behavior |
|---|---|---|
| Board USB CDC | COM port; displayed baud does not affect USB | Host controls the optional mirror with the `telemetry` CLI command |
| External UART | USART1 TX on PA9, 921600 8-N-1, 3.3 V logic | Always-on transmit stream; does not accept CLI commands |
| UDP bridge | External project configuration | Bridge behavior is not defined by SCV2 firmware |

## USB CDC

Connect the board using a USB data cable. The firmware's telemetry mirror is
controlled with `telemetry on`, `telemetry off`, and `telemetry toggle`; see
[USB CLI](../usb-cli/) for command behavior. Application-specific connection
steps belong to the
[dashboard setup guide](https://github.com/weiliangng/scv2-dashboard/blob/main/docs/SETUP.md).

## External USART1 receiver

1. Use a 3.3 V USB-to-UART adapter.
2. Connect adapter RX to PA9 and connect grounds.
3. Do not drive PA9 and do not apply 5 V logic.
4. Select baud rate `921600`.
5. Clear **Enable USB telemetry while connected** because USART1 streams continuously.

## UDP bridge

An external bridge may forward the USART1 stream over UDP. Its network and
forwarding behavior are not controlled by this firmware repository; consult
the bridge and dashboard repositories.

:::note[One owner per COM port]
The dashboard, PuTTY, CLion's serial monitor, and other serial tools cannot normally share the same COM port. Disconnect one before opening another.
:::

For desktop setup, executable packaging, and application troubleshooting, see
the canonical [dashboard setup guide](https://github.com/weiliangng/scv2-dashboard/blob/main/docs/SETUP.md).

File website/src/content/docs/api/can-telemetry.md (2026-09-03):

---
title: CAN telemetry
description: Decode SCV2's 8-byte Classic CAN fast telemetry and fault-status frame.
sidebar:
  order: 2
---

SCV2 transmits one Classic CAN frame containing fast electrical telemetry and fault status.

## Frame contract

| Property | Value |
|---|---|
| Format | Classic CAN data frame; not CAN FD or a remote frame |
| Identifier | Standard 11-bit ID `0x077` |
| DLC | 8 bytes |
| Bus rate | 1 Mbit/s |
| Nominal update rate | 1 kHz, task-scheduled and best effort |
| Multi-byte order | Little-endian; least-significant byte first |

A receiver must tolerate jitter and missing frames rather than assuming an exact one-millisecond arrival interval.

## Payload

| Bytes | Field | Raw type | Scale | Conversion |
|---|---|---|---|---|
| 0–1 | Load power | `uint16_t` | 0.1 W/count | `p_load_W = raw / 10.0` |
| 2–3 | Capacitor voltage | `uint16_t` | 0.1 V/count | `v_cap_V = raw / 10.0` |
| 4–5 | Converter-current command | Signed 16-bit two's complement | 0.1 A/count | `i_conv_A = signed_raw / 10.0` |
| 6 | Reserved | `uint8_t` | — | Ignore; currently zero |
| 7 | Status | `uint8_t` bitmask | — | Decode using the masks below |

Unsigned fields saturate to the range 0–6553.5 W/V. Converter current uses the signed 16-bit wire range, although the current control source clamps its command to ±10 A.

## Status byte

| Bit | Mask | Meaning when set |
|---:|---:|---|
| 0 | `0x01` | Vbus overvoltage fault latched |
| 1 | `0x02` | Vcap overvoltage fault latched |
| 2–7 | — | Reserved; ignore unknown bits |

Test individual masks instead of comparing the entire status byte with a fixed value. This keeps receivers compatible with future status bits.

## Portable C decoder

```c
#include <stdbool.h>
#include <stddef.h>
#include <stdint.h>

enum {
  SCV2_TELEMETRY_CAN_ID = 0x077u,
  SCV2_STATUS_VBUS_OVP = 1u << 0,
  SCV2_STATUS_VCAP_OVP = 1u << 1,
};

typedef struct {
  uint16_t p_load_dW;
  uint16_t v_cap_dV;
  int32_t i_conv_dA;
  uint8_t status;
  bool vbus_ovp;
  bool vcap_ovp;
} scv2_telemetry_t;

static uint16_t read_u16_le(const uint8_t *bytes)
{
  return (uint16_t)bytes[0] | ((uint16_t)bytes[1] << 8);
}

static int32_t read_i16_le(const uint8_t *bytes)
{
  const uint16_t raw = read_u16_le(bytes);
  return ((raw & 0x8000u) != 0u) ? ((int32_t)raw - 65536L) : (int32_t)raw;
}

bool Scv2Telemetry_Decode(uint32_t identifier,
                          bool is_extended_id,
                          bool is_remote_frame,
                          uint8_t dlc_bytes,
                          const uint8_t *data,
                          scv2_telemetry_t *telemetry)
{
  if ((identifier != SCV2_TELEMETRY_CAN_ID) || is_extended_id ||
      is_remote_frame || (dlc_bytes != 8u) ||
      (data == NULL) || (telemetry == NULL)) {
    return false;
  }

  telemetry->p_load_dW = read_u16_le(&data[0]);
  telemetry->v_cap_dV = read_u16_le(&data[2]);
  telemetry->i_conv_dA = read_i16_le(&data[4]);
  telemetry->status = data[7];
  telemetry->vbus_ovp = (data[7] & SCV2_STATUS_VBUS_OVP) != 0u;
  telemetry->vcap_ovp = (data[7] & SCV2_STATUS_VCAP_OVP) != 0u;
  return true;
}
```

Do not cast the payload directly to a packed C struct. Explicit decoding avoids alignment dependencies and makes wire endianness unambiguous.

## Worked frame

```text
88 13 2C 01 9C FF 00 03
```

- Load power: `0x1388 = 5000` → `500.0 W`
- Capacitor voltage: `0x012C = 300` → `30.0 V`
- Converter current: `0xFF9C = -100` → `-10.0 A`
- Reserved byte: `0x00`
- Status: `0x03` → both overvoltage flags are set

## Receiver checklist

1. Accept standard identifier `0x077` with DLC 8 on a 1 Mbit/s Classic CAN bus.
2. Reject extended, remote, and wrong-DLC frames.
3. Copy or decode the complete frame and record its arrival timestamp.
4. Publish it from the receive callback using the robot firmware's normal synchronization mechanism.
5. Keep fixed-point values until display or control boundaries when practical.
6. Ignore byte 6 and unknown status bits.
7. Detect stale telemetry using a timeout selected for the robot's safety requirements.

The canonical firmware-side receiver guide remains available in [`CAN_TELEMETRY.md`](https://github.com/weiliangng/scv2/blob/main/CAN_TELEMETRY.md).

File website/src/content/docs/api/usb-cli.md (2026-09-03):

---
title: USB CLI
description: Connect to SCV2 over USB CDC and use its diagnostic and control commands safely.
sidebar:
  order: 3
---

The USB CDC command-line interface exposes measurements, controller state, mode selection, manual control, and expert calibration functions.

:::danger[Power hardware]
Commands such as `ctrl`, `pset`, and `swen` change controller behavior. `gpio`, `dac`, and `cal` can directly affect hardware outputs or calibration. Use them only with a known circuit, a current-limited supply, a safe load, and an accessible shutdown method.
:::

## Connect

SCV2 appears on Windows 10 or 11 as `STM32 Virtual ComPort (COMx)` or `USB Serial Device (COMx)`. Use a USB data cable and configure the terminal as:

| Setting | Value |
|---|---|
| Connection | Serial |
| Port | Assigned SCV2 COM port |
| Speed | 115200 |
| Data bits | 8 |
| Stop bits | 1 |
| Parity | None |
| Flow control | None |

USB CDC does not physically depend on the selected baud rate; 115200 is the project convention.

## Safe first session

Enter:

```text
telemetry off
help
status
```

`status` is read-only and takes approximately one second because it averages 1,000 measurement samples. It reports mode, physical output pins, faults, lockouts, voltages, currents, energy, power setpoint, input-source state, and peripheral diagnostics.

## Command summary

| Command | Purpose | Risk level |
|---|---|---|
| `help` | Show available commands | Read-only |
| `status` | Print averaged controller and diagnostic state | Read-only |
| `telemetry on\|off\|toggle` | Control the USB `T1` telemetry mirror | Diagnostic |
| `ctrl external\|manual\|measure\|direct` | Select requested controller mode | Control |
| `pset <watts>` | Set manual power from −240 to +240 W | Control |
| `swen 0\|1` | Publish a manual switch-enable request | Control |
| `gpio write <PIN> <0\|1>` | Directly write an MCU GPIO | Expert |
| `gpio toggle <PIN>` | Toggle an MCU GPIO | Expert |
| `dac set <1\|3> <1\|2> <0..4095>` | Write a raw DAC value | Expert |
| `cal set <NAME> <VALUE>` | Change active calibration in RAM | Calibration |
| `cal load` | Replace active values with saved calibration | Calibration |
| `cal save` | Persist the active calibration set | Calibration |

## Controller modes

| Mode | Behavior |
|---|---|
| `external` | Fresh referee UART first, then fresh CAN, then no source. Default after boot. |
| `manual` | Persistent `pset` and `swen` values together with the physical pushbutton. |
| `measure` | Measurements continue while switch enable is forced off. |
| `direct` | Guarded power-stage GPIOs and DAC1 become available for expert bench control. |

Changing mode resets the pushbutton switch-enable request to off. Fault and undervoltage protection override all modes, including direct mode.

## Manual-operation pattern

Use only on an approved current-limited setup:

```text
swen 0
pset 80
ctrl manual
status
swen 1
status
swen 0
ctrl external
status
```

Always request `swen 0` before returning to external control, then verify the physical switch-enable output using `status`.

## Input behavior

- Commands and arguments are case-sensitive and normally lowercase.
- Calibration names are uppercase.
- GPIO names are case-insensitive; `PB4` and `b4` are equivalent.
- Up and Down browse history; normal cursor editing keys are supported.
- `Ctrl+C` cancels the current input line.
- Lines are limited to 119 characters and 15 tokens.

For the complete calibration-name list, GPIO guards, DAC behavior, workflows, and troubleshooting, use the canonical [`CLI_GUIDE.md`](https://github.com/weiliangng/scv2/blob/main/CLI_GUIDE.md).

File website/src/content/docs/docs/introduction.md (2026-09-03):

---
title: Introduction
description: Understand what SCV2 does and choose the right integration path.
sidebar:
  order: 1
---

SCV2 is a bidirectional switching converter that manages a physical supercapacitor energy buffer for power-limited robot chassis motors.

## The energy problem

The referee system limits chassis motor power from **50 W to 120 W** across robot levels 1 to 10. Its 60 J virtual buffer permits short periods above that limit, but excess power drains it quickly:

```text
60 W excess × 1 second = 60 J
```

When chassis demand falls below the limit, unused allowance refills the virtual buffer. A depleted buffer can trigger a five-second chassis shutdown.

## What SCV2 adds

SCV2 measures chassis voltage and current. When chassis power is below the referee limit, it uses the surplus to charge a supercapacitor bank. When demand rises above the limit, the bank supplies the difference.

A bank may store up to 2,000 J. After conversion losses and operating limits, expected usable energy is approximately **1,200–1,400 J**—enough to support transient loads such as acceleration, ramps, and slopes without depleting the referee buffer as quickly.

## Choose an integration path

| Goal | Start here |
|---|---|
| Mount and commission the hardware | [Installation](../installation/) |
| Confirm electrical limits | [Technical specifications](../specifications/) |
| Integrate robot control and telemetry | [Interfaces overview](../../api/overview/) |
| Receive fast CAN telemetry | [CAN telemetry](../../api/can-telemetry/) |
| Diagnose a board in the pit | [Debugging and testing](../../operations/debugging/) |

:::note[Port names]
**IN** is the chassis-bus side and **OUT** is the supercapacitor side. Because power flow is bidirectional, either port can source or sink power.
:::

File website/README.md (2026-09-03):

# SCV2 website

The public SCV2 website is built with Astro and Starlight. The custom homepage lives in `src/pages` and technical documentation lives in `src/content/docs` as Markdown.

## Local development

Use Node.js 24 or newer from this directory:

```powershell
npm install
npm run dev
```

Astro serves the project at `http://localhost:4321/scv2/` because the production site is a GitHub project page.

## Verification

```powershell
npm run build
```

The build performs Astro type and content checks, generates the static site in `dist`, and builds Starlight's search index.

## Publishing

The `pages.yml` workflow builds this directory and deploys its output. In the repository's **Settings → Pages → Build and deployment**, select **GitHub Actions** as the source.

The pre-migration website copy is preserved in [`../knowledge-base/legacy-website.md`](../knowledge-base/legacy-website.md).

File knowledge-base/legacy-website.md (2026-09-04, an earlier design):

# Legacy SCV2 website content

This file preserves the content of the original hand-written SCV2 website before the Astro and Starlight migration. It is a knowledge-base snapshot, not a published page. The source was the original documentation site introduced in commit `1dc9715`, including the later 97% peak-efficiency specification from commit `180e360`.

## Home

# SCV2 supercapacitor controller

SCV2 manages a physical energy buffer for power-limited robot chassis motors.

## Why an energy buffer is needed

The referee system limits chassis motor power from 50 W to 120 W across robot levels 1 to 10. It also provides a 60 J virtual power buffer for short periods above that limit.

When chassis power exceeds the limit, the virtual buffer drains by the excess power. For example, 60 W above the limit consumes 60 J in one second. When chassis power is below the limit, the unused allowance refills the buffer.

If a level 1 robot stops moving, the full 50 W allowance is available. The virtual buffer will refill in:

`60 J / 50 W = 1.2 s`

A depleted buffer can trigger a competition penalty which used to be HP loss, but now results in a temporary chassis shutdown for 5 seconds.

Figure: Chassis power fluctuates above and below the referee limit during a match (`chassis.png`).

## The physical buffer

SCV2 is a bidirectional switching converter that works with a supercapacitor bank of up to 2000 J. It is intended to behave like a larger version of the referee system's virtual buffer.

Chassis power is measured from voltage and current. When chassis power is below the referee limit, SCV2 uses the surplus to charge the capacitor bank. When chassis power exceeds the limit, the bank supplies the difference.

The converter supports constant input-power regulation and CC/CV charging. After conversion losses and operating limits, the expected usable energy is about 1200 to 1400 J. This supports short loads such as acceleration, ramps, and slopes without depleting the referee buffer as quickly.

## Specifications

**Port convention:** IN is the chassis-bus side and OUT is the supercapacitor side. Since power flow is bidirectional, each port can source or sink power.

| Port | Parameter | Range or limit |
|---|---|---|
| IN — chassis bus | Voltage range | 12 to 28 V |
| IN — chassis bus | Current limit | -10 to +10 A; programmable in debug mode |
| IN — chassis bus | Power setting | -240 to +240 W; programmable in 1 W steps |
| IN — chassis bus | Reverse-flow voltage limit | 26.2 V if the battery is disconnected or shuts down while reverse power is set |
| OUT — supercapacitor | Voltage range and setting | 5 to 30 V; digitally programmable |
| OUT — supercapacitor | Current limit | -15 to +15 A; fixed limits |
| Response | Chassis load-step settling time | <1 ms; 150 µs typical |
| Performance | Peak efficiency | Up to 97% |

**Power sign:** positive power flows from IN to OUT and charges the bank. Negative power flows from OUT to IN and supports the chassis bus.

Figures:

- Power transfer envelope at a 24 V chassis bus (`power-envelope-24v.png`).
- Maximum transfer magnitude across the specified voltage range (`maximum-power-transfer.png`).

## Protection and fault handling

> The hardware is designed to tolerate these events, but they are not recommended operating procedures.

- Hot-plugging the power source
- Hot-plugging a charged or discharged supercapacitor bank
- Short-circuit current limiting
- Overvoltage detection and shutdown on both ports
- IN-port undervoltage lockout
- Capacitor degradation detection with charge-voltage foldback when added energy does not produce the expected voltage rise

## Features

1. Robot-independent UART and CAN interfaces
2. USB CLI for field debugging and manual bank-capacity testing
3. Telemetry dashboard over wired USB serial or Wi-Fi UDP; Wi-Fi requires an additional transmitter
4. Normal installation does not require individual board calibration after initial flashing and soldering
5. No unintended backfeeding or "zombie power"; no isolation relay required

## Documentation links

- Physical installation
- Robot interface
- Debugging and testing
- FAQ

---

## Physical installation

> Confirm mounting, connector, fuse, and wiring details against the released hardware documents before applying power.

### Competition checklist

1. Secure the controller and capacitor bank.
2. Prevent cable strain and contact with conductive objects.
3. Check power polarity and connector seating.
4. Check the fuse, isolation, and shutdown arrangement.
5. Connect CAN and referee UART as required.
6. Commission with an approved current-limited setup.
7. Check status before enabling the power stage.

### Hardware details

Mounting dimensions, connector pinouts, and photographs are not yet included in the repository.

---

## Robot interface

External mode uses a fresh referee UART command first, then a fresh CAN command. With no fresh source, the controller selects no-source state.

### Connections

| Interface | Configuration | Use |
|---|---|---|
| Referee UART | USART3, 115200, 8-N-1, receive | Power limit and buffer energy |
| CAN | Classic CAN, 1 Mbit/s | Commands and telemetry |
| Telemetry UART | USART1, 921600, 8-N-1, transmit | `T1` CSV stream every 10 ms |
| USB | CDC virtual COM port | CLI and optional telemetry |

### CAN telemetry

SCV2 sends an 8-byte frame using standard identifier `0x077`.

The original page linked to `CAN_TELEMETRY.md` for the receiver guide.

---

## Debugging

### Dashboard

The dashboard displays the 69-field `T1` telemetry record. It supports USB serial, external UART, and UDP input.

The original page linked to a dashboard setup guide that has since moved to
the separate [`scv2-dashboard` repository](https://github.com/weiliangng/scv2-dashboard).

### Bank capacity

Use `cap_energy_mJ`, `cap_dE_mJ_min`, `cap_dV_mV_min`, and the derate fields during a controlled test.

A capacity test procedure and pass criteria are not yet documented.

The original page linked to the telemetry field reference in `agent.md`.

### USB CLI

Start with read-only commands:

```text
telemetry off
help
status
```

The original page linked to `CLI_GUIDE.md` for the complete guide.

---

## FAQ

### Why is switch enable off after a command was accepted?

Check for faults, undervoltage lockout, stale inputs, capacitor-voltage lockout, direction, and switching timers. Command acceptance does not override protection.

### Can the dashboard and CLI share one USB port?

No. Close one program before connecting the other.

### Where is the connector pinout?

It is not yet published. Use the released schematic and connector document.

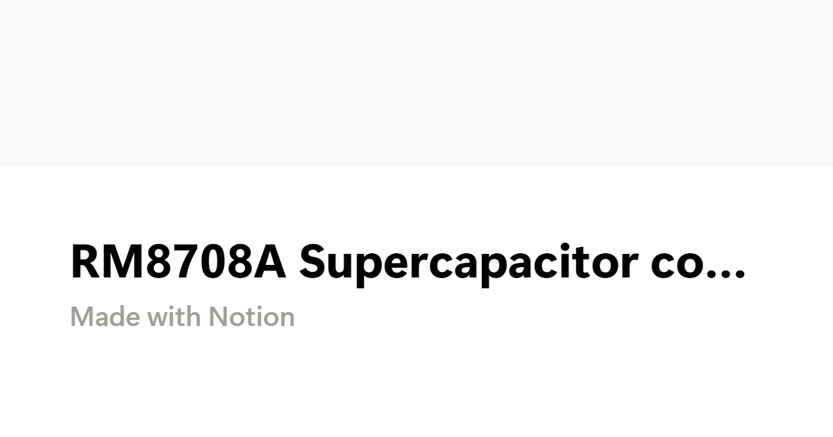
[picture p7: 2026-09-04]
knowledge-base/notion-rm8708a/assets/social-preview.png

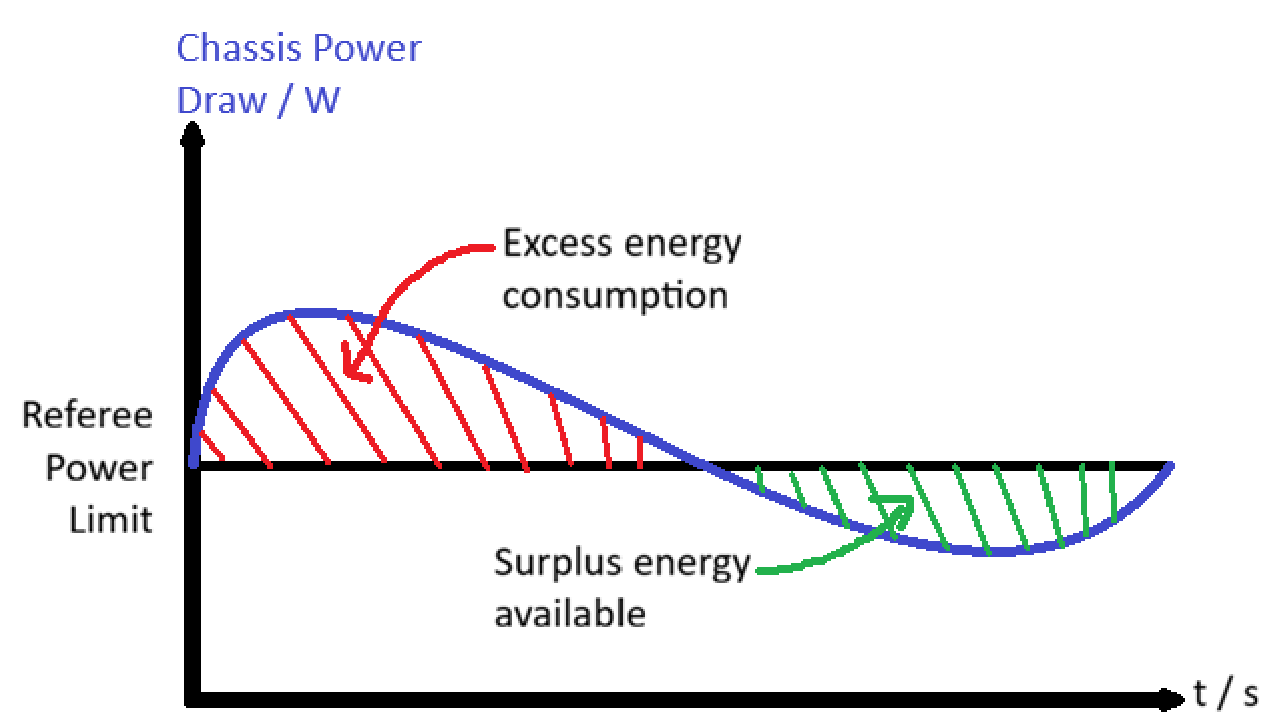
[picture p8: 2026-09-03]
website/public/assets/chassis.png

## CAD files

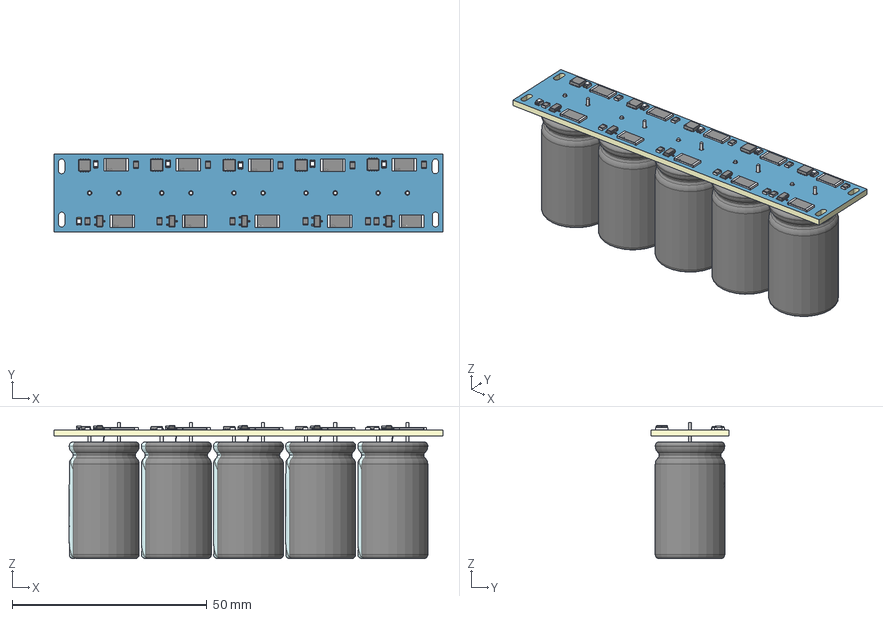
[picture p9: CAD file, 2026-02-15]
3D_pancake_bank.step
100.0 x 20.0 x 35.0 mm
Board~HsGZ
TopCopper~HsGZ
BottomCopper~HsGZ
TopFpcStiffener~HsGZ
BottomFpcStiffener~HsGZ
LED0805-R-RD~LED0805-RD~HsGZ x 6
R0805~R0805_L2.0-W1.3-H0.6~HsGZ x 11
SOT-23-3_L2.9-W1.6-P1.90-LS2.8-BR~SOT-23-3L_ L2.9-W1.6-H1.1-LS2.8-P0.95~HsGZ x 5
DFN-8_L3.1-W3.0-P0.65-LS3.3-BL~DFN-8_L3.1-W3.0-P0.65-LS3.3-BL~HsGZ x 5
CAP-TH_BD18.0-P7.50-D0.8-FD~CAP-TH_BD18.0-H30.0-P7.5~HsGZ x 5
R2512~R2512_L6.3-W3.2-H0.6~HsGZ x 10

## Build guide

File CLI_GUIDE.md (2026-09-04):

# SCV2 USB CLI setup and usage guide

This guide explains how to connect to the SCV2 controller's command-line interface (CLI) from a Windows 10 or Windows 11 PC. It assumes that the current SCV2 firmware is already installed on the board. No programming experience is required.

The CLI can display measurements and controller state, select a control source, and change power-stage or calibration settings. Some commands can enable or directly control power hardware, so read the safety section before using anything beyond `help`, `status`, and `telemetry`.

## What you need

- A Windows 10 or Windows 11 PC
- The SCV2 board with current firmware installed
- A USB **data** cable that fits the board; a charge-only cable will not work
- [PuTTY](https://www.chiark.greenend.org.uk/~sgtatham/putty/latest.html), used here as the serial terminal
- A known-safe, current-limited bench setup before using control, GPIO, DAC, or calibration commands

Only one program can normally use a COM port at a time. Close the SCV2 dashboard, another PuTTY window, CLion's serial monitor, and any other serial-terminal program before connecting.

## Safety first

The following commands are read-only or only change whether diagnostic telemetry is printed over USB:

```text
help
status
telemetry on
telemetry off
telemetry toggle
```

Commands such as `ctrl`, `pset`, and `swen` can change controller behavior. The `gpio`, `dac`, and `cal` commands can directly change hardware outputs or calibration. Use them only with an understood circuit, a current-limited supply, a safe load, and a shutdown method within reach.

An `ok` response means that the firmware accepted the command. It does not prove that a requested physical output changed. Fault handling, undervoltage lockout, controller policy, and output timing can override a request. Run `status` and check the real hardware when verification matters.

## 1. Install PuTTY

1. Open the [official PuTTY download page](https://www.chiark.greenend.org.uk/~sgtatham/putty/latest.html).
2. Under **MSI (Windows Installer)**, download the 64-bit x86 installer for a normal Intel or AMD Windows PC. Use the Arm installer only if the PC runs Windows on Arm.
3. Open the downloaded `.msi` file.
4. Accept the default installation options and finish the installer.
5. Open the Start menu and search for **PuTTY** to confirm it was installed.

Do not download PuTTY from an unofficial software-download site.

## 2. Install or verify the virtual COM-port driver

The SCV2 firmware identifies itself as a USB Communications Device Class (CDC) device named `STM32 Virtual ComPort`. Windows 10 and Windows 11 contain the correct Microsoft `usbser.sys` driver and should install it automatically when the board is connected. A separate ST driver download is not normally needed.

ST's older `STSW-STM32102` package is intended for Windows 8.x and earlier. ST specifically recommends the native Windows driver starting with Windows 10. See the official [Microsoft USB device-class driver documentation](https://learn.microsoft.com/en-us/windows-hardware/drivers/usbcon/supported-usb-classes) and [ST virtual COM-port driver notice](https://www.st.com/en/development-tools/stsw-stm32102.html).

To connect and find the assigned port:

1. Power the board as required by the hardware setup.
2. Connect the board's USB device port directly to the PC with a USB data cable.
3. Wait a few seconds while Windows configures the device.
4. Right-click the Windows Start button and open **Device Manager**.
5. Expand **Ports (COM & LPT)**.
6. Look for `STM32 Virtual ComPort (COMx)` or `USB Serial Device (COMx)`. Record the complete port name, such as `COM8`.

The COM number is assigned by Windows and may differ between PCs or USB sockets. Never assume that an example such as `COM8` is the correct port.

If no new port appears, see [Troubleshooting](#troubleshooting) before installing any third-party driver.

## 3. Open the CLI in PuTTY

1. Start PuTTY.
2. In the **Session** screen, select **Serial** as the connection type.
3. Set **Serial line** to the port found in Device Manager, for example `COM8`.
4. Set **Speed** to `115200`.
5. In the left navigation tree, open **Connection > Serial** and verify:
   - **Speed (baud):** `115200`
   - **Data bits:** `8`
   - **Stop bits:** `1`
   - **Parity:** `None`
   - **Flow control:** `None`
6. Return to **Session** and select **Open**.

The CLI uses USB CDC rather than a physical UART, so the selected baud rate does not change the actual USB transfer speed. `115200` is the project convention and is safe to use. The separate USART1 telemetry output on PA9 uses `921600` baud and does not accept CLI commands.

After opening the port, the terminal may show:

```text
CLI ready. Type 'help'.
scv2>
```

If the board finished booting before PuTTY connected, the startup message may already have been discarded. Press Enter once to display a fresh `scv2>` prompt.

## 4. First connection

Enter these commands one at a time, pressing Enter after each line:

```text
telemetry off
help
status
```

`telemetry off` keeps the interactive terminal readable. The USB telemetry mirror is off after a normal reboot, but explicitly disabling it avoids CSV records becoming mixed with prompts and command output.

`status` is read-only. It averages 1,000 measurement samples with a 1 ms delay, so its response takes about one second. It reports:

- The selected controller mode and physical output-pin states
- Safety faults and undervoltage lockout
- Bus voltage, capacitor voltage, currents, energy, and power setpoint
- CAN, UART, manual-command, and pushbutton state
- USB, USART1, CAN, ADC, DAC, and interrupt diagnostics

The `Current mode` line shows the controller's resolved decision, which can differ from the mode requested with `ctrl`. For example, external mode with no fresh command source reports `no-source`.

## Entering and editing commands

- Command names and their arguments are case-sensitive. Use the lowercase spellings shown in this guide.
- Calibration names are uppercase, for example `A_VBUS`.
- GPIO pin names are case-insensitive and may include or omit the leading `P`; `PB4` and `b4` are equivalent to the parser.
- The Up and Down arrow keys browse command history.
- Left, Right, Home, End, Backspace, and Delete support normal line editing.
- `Ctrl+C` cancels the current input line.
- A command line can contain at most 119 characters and at most 15 command/argument tokens.
- An invalid command name produces `unknown command: <name>`. Invalid arguments normally produce a `usage:` or `err:` message.

## Command reference

### `help`

```text
help
```

Prints the main command list. Two internally dispatched names, `mode` and `dir`, are intentionally absent from that list because their former direct controls are unavailable.

### `status`

```text
status
```

Prints the read-only controller and diagnostic snapshot described above. Allow about one second for the averaging operation to finish.

### `telemetry`

```text
telemetry on
telemetry off
telemetry toggle
```

Controls the `T1` telemetry mirror on the same USB connection as the CLI:

- `on` starts a telemetry record approximately every 10 ms.
- `off` stops the USB mirror and is recommended for interactive CLI use.
- `toggle` changes the current setting.

This command never stops the separate, always-on USART1 telemetry output. When USB telemetry is enabled, `T1,...` CSV lines are expected to appear between the prompt and command responses.

For a graphical telemetry view, use the separate
[SCV2 Dashboard setup guide](https://github.com/weiliangng/scv2-dashboard/blob/main/docs/SETUP.md).

### `ctrl`

```text
ctrl external
ctrl manual
ctrl measure
ctrl direct
```

Selects the controller's requested operating mode:

| Argument | Purpose |
|---|---|
| `external` | Uses fresh referee UART power and energy first, otherwise fresh CAN, otherwise no source. This is the default mode after boot. |
| `manual` | Uses the persistent values set by `pset` and `swen`, together with the physical pushbutton. |
| `measure` | Keeps measurements running while forcing switch enable off. |
| `direct` | Leaves guarded power-stage GPIOs and DAC1 available for direct bench control. This is an expert-only mode. |

Changing the requested mode resets the pushbutton switch-enable request to off. Fault and undervoltage handling still override every mode, including direct mode.

### `pset`

```text
pset <watts>
```

Publishes a manual power setpoint from `-240` through `240` watts. Examples:

```text
pset 80
pset -50
pset 0
```

The value only controls power while manual mode is selected. It does not select manual mode and does not enable the power stage. If no value has been set since boot, manual mode uses a 50 W default. The mailbox value remains present until the board resets or another `pset` command replaces it.

### `swen`

```text
swen 0
swen 1
```

Publishes a persistent manual switch-enable request:

- `0` requests off.
- `1` requests on.

It only affects output selection in manual mode. The most recent manual `swen` command or physical pushbutton event wins. Safety, undervoltage lockout, and the firmware's output timing can still keep the physical SWEN output off.

### `gpio` — expert use only

```text
gpio write <PIN> <0|1>
gpio toggle <PIN>
```

Examples of valid syntax:

```text
gpio write PB4 0
gpio toggle PA10
```

The parser accepts MCU ports A through G and pin numbers 0 through 15, but this is **not** a list of safe pins. A syntactically valid pin may be an input, may belong to a peripheral, or may be critical to the board.

The following guarded power-stage pins require `ctrl direct` before they can be written or toggled:

| Pin | Firmware name |
|---|---|
| `PB1` | DIR |
| `PB4` | SWEN |
| `PB5` | MODEMSB |
| `PB6` | MODELSB |
| `PA10` | LED |

Other pins do not receive this direct-mode protection. Do not experiment with arbitrary GPIO numbers.

### `dac` — expert use only

```text
dac set <1|3> <1|2> <0..4095>
```

Writes a raw 12-bit value to DAC1 or DAC3, channel 1 or 2. For example:

```text
dac set 3 1 920
```

DAC1 writes require `ctrl direct`. DAC3 writes do not. A raw value of 0 corresponds approximately to 0 V and 4095 approximately to 3.3 V, but the electrical effect depends on where the DAC output is connected in the circuit.

A `dac set` value is normally volatile. On reboot, DAC3 uses the saved `DAC3_CH1_BOOT_U12` and `DAC3_CH2_BOOT_U12` calibration values; DAC1 returns to firmware-controlled startup behavior.

### `cal` — calibration use only

```text
cal set <NAME> <VALUE>
cal load
cal save
```

`cal set` changes one active value in RAM. The accepted names are:

```text
A_VBUS B_VBUS A_ILOAD B_ILOAD MIDPOINT
A_INP B_INP A_INN B_INN
A_VCAP B_VCAP
A_OP B_OP A_ON B_ON
DAC3_CH1_BOOT_U12 DAC3_CH2_BOOT_U12
```

Floating-point values must be finite. `A_VBUS` must also be nonzero. The two DAC3 boot values must be integers from 0 through 4095 and are applied to the physical DAC immediately.

`cal save` writes the complete active calibration set to emulated EEPROM in flash. `cal load` replaces active RAM values with the saved set and applies both saved DAC3 boot outputs. If no valid saved set exists, `cal load` prints `err: no valid saved cal`.

There is no read-only command that prints the active calibration set without first loading it. A successful `cal load` prints the values it loaded, but it also discards any unsaved RAM changes. Do not use it as an inspection command when unsaved work must be preserved.

### Unavailable legacy commands

Entering either of these names:

```text
mode
dir
```

returns:

```text
unavailable: main mode control is staged off
```

They do not change the controller. The guarded `gpio` interface in direct mode is the current low-level mechanism.

## Safe example workflows

### Observe the board without changing control

```text
telemetry off
status
```

This is the recommended first workflow and is safe for routine diagnosis.

### Manual operation with an explicit shutdown

Only perform this workflow on an approved, current-limited bench setup:

```text
swen 0
pset 80
ctrl manual
status
swen 1
status
swen 0
ctrl external
status
```

Set the manual SWEN request to off before selecting manual mode. Confirm the `Switch enable output (SWEN) pin` line before and after enabling. Always issue `swen 0` before returning to external control.

### Direct GPIO or DAC1 work

Direct mode does not automatically clear every stage output when entered. Plan every pin/value change and the shutdown sequence before starting:

```text
ctrl direct
gpio write PB4 0
# perform only the previously planned GPIO or DAC operations
gpio write PB4 0
ctrl external
status
```

The line beginning with `#` is an explanation, not a CLI command; do not paste it into the terminal. Put every altered output into its intended safe state before leaving direct mode.

### Calibration session

1. Record a `status` snapshot and the existing approved calibration values before changing anything.
2. Use `cal set` for one value at a time.
3. Validate the resulting measurements with suitable bench equipment.
4. Repeat until the complete active set is known-good.
5. Run `cal save` only after all active values have been verified.
6. Reboot or use `cal load`, then verify that the saved values behave as expected.

## Ending a session

Before closing PuTTY after any manual or direct-control work:

1. Request `swen 0` when using manual mode, or explicitly clear PB4 in direct mode.
2. Return to the required normal mode, usually `ctrl external`.
3. Run `status` and confirm the physical SWEN output is off or otherwise in the intended state.
4. Close the PuTTY window.

Closing PuTTY only releases the PC's COM port. It does not reset the board, clear manual mailbox values, change the selected controller mode, or automatically disable hardware.

## Troubleshooting

### No COM port appears in Device Manager

- Confirm the board is powered.
- Try a cable known to carry data; many inexpensive USB cables only provide power.
- Try a different USB socket on the PC and avoid an unpowered hub.
- Disconnect the board, note the existing COM ports, reconnect it, and watch which entry appears.
- Check **Other devices** and **Universal Serial Bus controllers** for an entry with a warning symbol.
- Right-click the problem device, choose **Update driver**, then **Search automatically for drivers**. Also allow Windows Update to finish pending driver updates.
- If available, try the board and cable on another Windows 10/11 PC to separate a board/cable fault from a PC configuration problem.

Do not install the legacy ST VCP package as the first fix on Windows 10 or Windows 11.

### PuTTY reports that it cannot open the serial port

- Recheck the COM number after reconnecting the board; Windows may assign a different number.
- Close the dashboard, other PuTTY sessions, CLion monitors, and any application using the port.
- Disconnect and reconnect the board, then reopen PuTTY.
- If the board reset or disappeared, close the old PuTTY session before trying again.

### PuTTY opens but the window is blank

- Press Enter once. The board may have printed its startup message before PuTTY connected.
- Confirm that PuTTY is using **Serial**, not SSH or Telnet.
- Confirm that the selected COM port belongs to the SCV2 board.
- Reconnect the USB cable and wait for the port to reappear.

### Typed characters do not appear or commands do not run

- Set PuTTY flow control to **None**.
- Confirm that the correct COM port is open.
- Press `Ctrl+C`, then Enter, to cancel a partially entered line and recover a prompt.
- Disconnect other software that may be writing commands to the same device.

### `T1,...` lines continuously cover the prompt

USB telemetry is enabled. Type:

```text
telemetry off
```

The command may appear mixed into a telemetry line while you type, but the firmware still receives it. If necessary, type it carefully and press Enter once.

### A command prints `usage:`

The spelling, number of arguments, or numeric range is invalid. Command words are case-sensitive. Run `help` and compare the command with the examples in this guide.

### A GPIO or DAC1 command says that direct mode is required

The firmware is protecting a power-stage output. Do not bypass the check until the direct operation and a safe shutdown sequence have been planned. On an approved bench setup, select `ctrl direct`, perform only the planned changes, restore safe outputs, and leave direct mode.

### `swen 1` returns `ok` but the output remains off

Check all of the following in `status`:

- The controller must be in manual mode for the manual SWEN mailbox to be selected.
- `Safety flag (is_safe)` must indicate a safe measurement state.
- No fault may be latched.
- Undervoltage lockout must be clear.
- The physical pushbutton may have published a newer off request.
- Minimum on/off timing may delay a transition briefly.

The physical `Switch enable output (SWEN) pin` line is the relevant confirmation; `ok` only confirms command acceptance.

## Related documentation

- [SCV2 Dashboard setup guide](https://github.com/weiliangng/scv2-dashboard/blob/main/docs/SETUP.md)
- [Downstream CAN telemetry receiver guide](CAN_TELEMETRY.md)
- [`agent.md`](agent.md), the advanced firmware, telemetry, and bench-test reference

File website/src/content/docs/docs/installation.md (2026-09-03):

---
title: Installation
description: Safely mount, wire, and commission an SCV2 controller and capacitor bank.
sidebar:
  order: 2
---

:::caution[Verify released hardware documents]
Confirm mounting dimensions, connector pinouts, fuse selection, polarity, and wiring against the released schematic and connector documents before applying power. Those hardware-specific details are not yet published in this repository.
:::

## Before you begin

Prepare:

- An SCV2 controller with current firmware
- A compatible 5–30 V supercapacitor bank
- A 12–28 V chassis bus or current-limited commissioning supply
- Correctly rated wiring, connectors, fuse, and shutdown arrangement
- CAN and/or referee UART wiring required by the robot
- A USB data cable for initial diagnostics

## Mechanical installation

1. Secure the controller and capacitor bank so neither can move under chassis acceleration or impact.
2. Prevent cable strain at every connector.
3. Keep exposed conductors away from the chassis and other conductive objects.
4. Route signal wiring away from high-current switching paths where practical.
5. Make the normal shutdown method accessible before testing.

## Electrical checklist

1. Confirm the chassis bus is within the 12–28 V input range.
2. Confirm the capacitor bank is within the 5–30 V output range.
3. Check the polarity of both power ports before inserting connectors.
4. Verify the fuse, isolation, and shutdown arrangement.
5. Connect CAN at 1 Mbit/s and referee UART at 115200 8-N-1 as required.
6. Connect USB only with a known data-capable cable.

See [Technical specifications](../specifications/) before selecting supplies, loads, wiring, or protection components.

## First power-up

1. Start with a current-limited supply and a known-safe load.
2. Keep the power-stage switch-enable request off.
3. Connect the USB CLI and enter:

   ```text
   telemetry off
   help
   status
   ```

4. Verify measured bus voltage, capacitor voltage, safety state, faults, and physical switch-enable output.
5. Confirm the selected control source is the one expected by the robot.
6. Enable the power stage only after the reported state and physical wiring agree.

:::danger[Command acceptance is not output confirmation]
An `ok` response only means firmware accepted a command. Fault handling, undervoltage lockout, controller policy, and output timing can still prevent a requested physical output. Verify with `status` and the actual hardware.
:::

## Final competition check

- Controller and bank are secure
- Cables cannot pull against connectors
- Power polarity and connector seating are correct
- Fuse and shutdown path are verified
- CAN and referee UART connections are correct
- Controller reports no unexpected faults
- Robot software detects stale or missing telemetry safely

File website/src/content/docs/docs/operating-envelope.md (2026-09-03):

---
title: Operating envelope
description: Understand the input-current, output-current, and power limits across the voltage range.
sidebar:
  order: 2
---

SCV2 transfer capability is bounded by chassis-bus current, supercapacitor current, and the 240 W power setting limit. The active constraint changes with port voltage.

## At a 24 V chassis bus

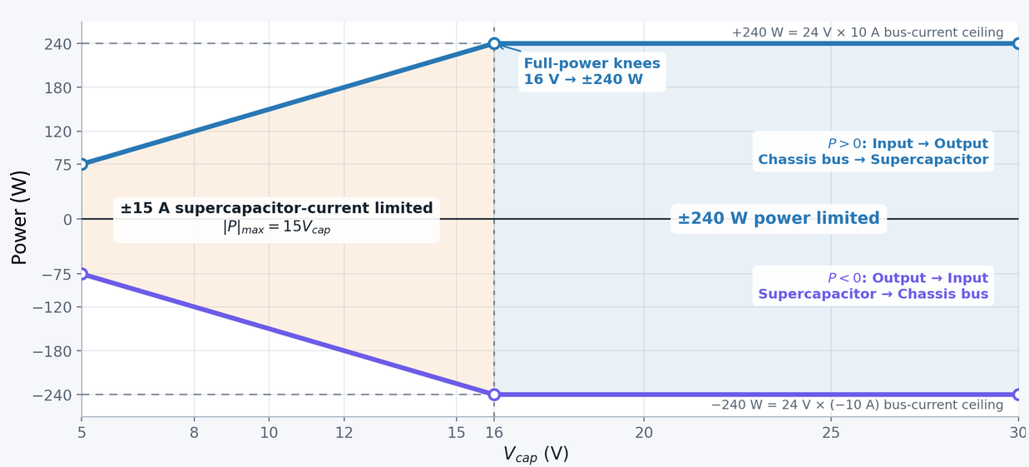
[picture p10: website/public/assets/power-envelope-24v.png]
SCV2 power transfer envelope at a 24 V chassis bus. Transfer is limited by 15 A supercapacitor current below 16 V and by 240 W above 16 V.


Below approximately 16 V at the supercapacitor port, the ±15 A OUT-port current limit bounds transferable power. At higher capacitor voltage, the ±240 W power limit becomes dominant.

## Across the specified voltage range

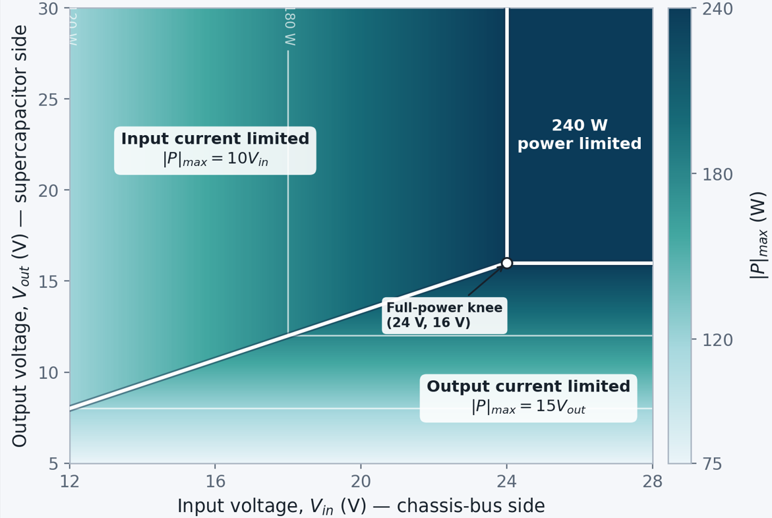
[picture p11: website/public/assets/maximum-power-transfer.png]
Maximum SCV2 power transfer by chassis-bus voltage and supercapacitor voltage, showing input-current, output-current, and 240 W limits.


Use the lower magnitude imposed by:

1. The ±10 A chassis-bus current limit
2. The ±15 A supercapacitor current limit
3. The ±240 W programmed power limit

:::note
These diagrams describe maximum transfer magnitude. Actual operation can be reduced by control policy, voltage limits, protection state, thermal conditions, or capacitor degradation foldback.
:::

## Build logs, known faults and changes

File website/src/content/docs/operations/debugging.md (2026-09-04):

---
title: Debugging and testing
description: Diagnose SCV2 using status, live telemetry, the dashboard, and controlled capacity tests.
sidebar:
  order: 1
---

Start diagnosis with observation. Do not change control or calibration until the reported measurements, mode, and protection state are understood.

## First response

1. Stop other programs that may own the SCV2 COM port.
2. Open the [USB CLI](../../api/usb-cli/).
3. Run:

   ```text
   telemetry off
   status
   ```

4. Record the complete output before changing state.
5. Check faults, undervoltage lockout, stale inputs, capacitor-voltage lockout, direction, and switching timers.

## Graphical telemetry

SCV2 provides the `T1` stream over board USB CDC and external USART1. Use
[Telemetry transports](../../api/telemetry/) for the firmware-owned interface
details. The separate
[dashboard repository](https://github.com/weiliangng/scv2-dashboard) owns the
desktop application, packaging, connection workflow, and troubleshooting.

## Switch enable remains off

An accepted command does not override protection. In `status`, confirm:

- The selected mode consumes the command source you are using
- `Safety flag (is_safe)` reports a safe measurement state
- No fault is latched
- Undervoltage lockout is clear
- The capacitor voltage permits the requested direction
- The physical pushbutton has not published a newer off request
- Minimum on/off timing is not delaying the transition

The physical `Switch enable output (SWEN) pin` line is the relevant confirmation.

## Bank-capacity investigation

During a controlled test, inspect:

- `cap_energy_mJ`
- `cap_dE_mJ_min`
- `cap_dV_mV_min`
- Capacitor derate fields

:::caution
A complete capacity-test procedure and pass criteria are not yet published. Do not infer a safe pass/fail threshold from a single telemetry field.
:::

## Further reference

- [Dashboard setup and operation](https://github.com/weiliangng/scv2-dashboard/blob/main/docs/SETUP.md)
- [Complete USB CLI guide](https://github.com/weiliangng/scv2/blob/main/CLI_GUIDE.md)
- [Advanced firmware and telemetry reference](https://github.com/weiliangng/scv2/blob/main/agent.md)

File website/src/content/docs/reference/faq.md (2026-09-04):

---
title: Frequently asked questions
description: Answers to common SCV2 installation, interface, and diagnostic questions.
sidebar:
  order: 1
---

## Why is switch enable off after a command was accepted?

Check faults, undervoltage lockout, stale inputs, capacitor-voltage lockout, power direction, and switching timers. An `ok` response confirms command acceptance only; it does not override protection or prove that the physical output changed.

Use `status` and inspect the physical `Switch enable output (SWEN) pin` line.

## Can the dashboard and CLI share one USB port?

Not as separate applications. Only one program can normally own a COM port. Close or disconnect the dashboard before opening PuTTY or another terminal.

The separate dashboard application provides an integrated CLI transaction for
this use case; see its
[setup and operation guide](https://github.com/weiliangng/scv2-dashboard/blob/main/docs/SETUP.md).

## Where is the connector pinout?

It is not yet published in this repository. Use the released schematic and connector document before wiring the controller.

## Does USB baud rate affect transfer speed?

No. The CLI uses USB CDC, so the terminal's baud selection does not change physical USB transfer speed. Use 115200 as the project convention. The separate USART1 telemetry output physically operates at 921600 baud.

## Why does external mode report no source?

External mode requires a fresh referee UART or CAN command. It prefers fresh referee UART, then fresh CAN, and enters no-source state if neither source is fresh.

## Can hot-plugging be used as the normal power switch?

No. The hardware is designed to tolerate hot-plug events, but they are not recommended operating procedures. Use the approved fuse, isolation, and shutdown arrangement.

## Does SCV2 need calibration after every installation?

Normal installation does not require individual board calibration after the board has received its initial approved flashing, soldering, and calibration process.

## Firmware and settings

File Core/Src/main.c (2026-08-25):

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
/* Includes ------------------------------------------------------------------*/
#include "main.h"
#include "cmsis_os.h"
#include "usb_device.h"

/* USER CODE BEGIN Includes */
#include <stdbool.h>
#include <stdio.h>

#include "task_dbg_over_usb.h"
#include "usb_cli.h"
#include "app_constants.h"
#include "can_protocol.h"
#include "capacitor_monitor.h"
#include "command_inputs.h"
#include "shared_state.h"
#include "telemetry_uart.h"
#include "telemetry_slow_adc_task.h"
#include "referee_uart.h"
#include "nvm_eeprom.h"
#include "stm32g4xx_ll_dac.h"
#include "scap_io_owner.h"
#include "app_watchdog.h"

/* USER CODE END Includes */

ADC_HandleTypeDef hadc1;
ADC_HandleTypeDef hadc2;
DMA_HandleTypeDef hdma_adc1;
DMA_HandleTypeDef hdma_adc2;

COMP_HandleTypeDef hcomp4;

DAC_HandleTypeDef hdac1;
DAC_HandleTypeDef hdac3;

FDCAN_HandleTypeDef hfdcan1;

IWDG_HandleTypeDef hiwdg;

OPAMP_HandleTypeDef hopamp1;
OPAMP_HandleTypeDef hopamp2;
OPAMP_HandleTypeDef hopamp3;

TIM_HandleTypeDef htim2;

UART_HandleTypeDef huart1;
UART_HandleTypeDef huart3;
DMA_HandleTypeDef hdma_usart1_tx;
DMA_HandleTypeDef hdma_usart3_rx;

osThreadId defaultTaskHandle;
uint32_t defaultTaskBuffer[ 128 ];
osStaticThreadDef_t defaultTaskControlBlock;
osThreadId usbCDCTxTaskHandle;
uint32_t usbCDCTxTaskBuffer[ 256 ];
osStaticThreadDef_t usbCDCTxTaskControlBlock;
osThreadId telemetryTaskHandle;
uint32_t telemetryTaskBuffer[ 512 ];
osStaticThreadDef_t telemetryTaskControlBlock;
osThreadId slowAdcTaskHandle;
uint32_t myTask04Buffer[ 128 ];
osStaticThreadDef_t myTask04ControlBlock;
osThreadId cliTaskHandle;
uint32_t myTask05Buffer[ 2048 ];
osStaticThreadDef_t myTask05ControlBlock;
osThreadId uartParsingTaskHandle;
uint32_t myTask06Buffer[ 256 ];
osStaticThreadDef_t myTask06ControlBlock;
void SystemClock_Config(void);
static void MX_GPIO_Init(void);
static void MX_DMA_Init(void);
static void MX_ADC1_Init(void);
static void MX_ADC2_Init(void);
static void MX_FDCAN1_Init(void);
static void MX_DAC1_Init(void);
static void MX_DAC3_Init(void);
static void MX_OPAMP1_Init(void);
static void MX_OPAMP2_Init(void);
static void MX_OPAMP3_Init(void);
static void MX_COMP4_Init(void);
static void MX_TIM2_Init(void);
static void MX_USART3_UART_Init(void);
static void MX_USART1_UART_Init(void);
static void MX_IWDG_Init(void);
void StartDefaultTask(void const * argument);
void StartUsbCDCTxTask(void const * argument);
void StartTelemetryTask(void const * argument);
void StartSlowAdcTask(void const * argument);
void StartCliTask(void const * argument);
void StartUartParsingTask(void const * argument);

/* USER CODE BEGIN 0 */
static void CycleCountWatchdog_Init(void)
{
  CoreDebug->DEMCR |= CoreDebug_DEMCR_TRCENA_Msk;
  DWT->CYCCNT = 0U;
  DWT->CTRL |= DWT_CTRL_CYCCNTENA_Msk;
}

static void AppDac3_InitDefaults(void)
{
  (void)HAL_DAC_SetValue(&hdac3, DAC_CHANNEL_1, DAC_ALIGN_12B_R, DAC3_CH1_BOOT_U12);
  (void)HAL_DAC_SetValue(&hdac3, DAC_CHANNEL_2, DAC_ALIGN_12B_R, DAC3_CH2_BOOT_U12);
  (void)HAL_DAC_SetValue(&hdac1, DAC_CHANNEL_1, DAC_ALIGN_12B_R, 2500u);
  (void)HAL_DAC_SetValue(&hdac1, DAC_CHANNEL_2, DAC_ALIGN_12B_R, 2500u);
}

/* USER CODE END 0 */

/**
  * @brief  The application entry point.
  * @retval int
  */
int main(void)
{

  /* USER CODE BEGIN 1 */
  const bool was_iwdg_reset = (__HAL_RCC_GET_FLAG(RCC_FLAG_IWDGRST) != RESET);
  __HAL_RCC_CLEAR_RESET_FLAGS();
  if (was_iwdg_reset){while (1){}}//hang forever
  /* USER CODE END 1 */

  /* MCU Configuration--------------------------------------------------------*/

  /* Reset of all peripherals, Initializes the Flash interface and the Systick. */
  HAL_Init();

  /* Configure the system clock */
  SystemClock_Config();

  /* USER CODE BEGIN SysInit */
  (void)NvmEeprom_Init();
  AppConstants_InitFromNvm();

  /* USER CODE END SysInit */

  /* Initialize all configured peripherals */
  MX_GPIO_Init();
  MX_DMA_Init();
  MX_ADC1_Init();
  MX_ADC2_Init();
  MX_FDCAN1_Init();
  MX_DAC1_Init();
  MX_DAC3_Init();
  MX_OPAMP1_Init();
  MX_OPAMP2_Init();
  MX_OPAMP3_Init();
  MX_COMP4_Init();
  MX_TIM2_Init();
  MX_USART3_UART_Init();
  MX_USART1_UART_Init();
  MX_IWDG_Init();
  /* USER CODE BEGIN 2 */
  AppWatchdog_Init(&hiwdg);
  CapacitorMonitor_Init();
  ScapIo_Init();
  CycleCountWatchdog_Init();
  DbgUsb_Init();
  TelemetryUart_Init(&huart1);
  UsbCli_Init();
#if USE_HAL_FDCAN_REGISTER_CALLBACKS == 1
  if (HAL_FDCAN_RegisterRxFifo0Callback(&hfdcan1, HAL_FDCAN_RxFifo0Callback) != HAL_OK)
  {
    Error_Handler();
  }
#endif
  if (HAL_FDCAN_ConfigInterruptLines(&hfdcan1, FDCAN_IT_GROUP_RX_FIFO0, FDCAN_INTERRUPT_LINE0) != HAL_OK)
  {
    Error_Handler();
  }
  if (HAL_FDCAN_ConfigInterruptLines(&hfdcan1, FDCAN_IT_GROUP_PROTOCOL_ERROR, FDCAN_INTERRUPT_LINE0) != HAL_OK)
  {
    Error_Handler();
  }
  if (HAL_FDCAN_ActivateNotification(&hfdcan1,
                                      FDCAN_IT_RX_FIFO0_NEW_MESSAGE | FDCAN_IT_BUS_OFF,
                                      0u) != HAL_OK)
  {
    Error_Handler();
  }
  if (HAL_FDCAN_Start(&hfdcan1) != HAL_OK)
  {
    Error_Handler();
  }
  if (HAL_DAC_Start(&hdac1, DAC_CHANNEL_1) != HAL_OK)
  {
    Error_Handler();
  }
  if (HAL_DAC_Start(&hdac1, DAC_CHANNEL_2) != HAL_OK)
  {
    Error_Handler();
  }
  if (HAL_DAC_Start(&hdac3, DAC_CHANNEL_1) != HAL_OK)
  {
    Error_Handler();
  }
  if (HAL_DAC_Start(&hdac3, DAC_CHANNEL_2) != HAL_OK)
  {
    Error_Handler();
  }
  AppDac3_InitDefaults();
  if (HAL_OPAMP_Start(&hopamp1) != HAL_OK)
  {
    Error_Handler();
  }
  if (HAL_OPAMP_Start(&hopamp2) != HAL_OK)
  {
    Error_Handler();
  }
  if (HAL_OPAMP_Start(&hopamp3) != HAL_OK)
  {
    Error_Handler();
  }
  if (HAL_COMP_Start(&hcomp4) != HAL_OK)
  {
    Error_Handler();
  }

  if (HAL_ADCEx_Calibration_Start(&hadc1, ADC_SINGLE_ENDED) != HAL_OK)
  {
    Error_Handler();
  }
  if (HAL_ADCEx_Calibration_Start(&hadc2, ADC_SINGLE_ENDED) != HAL_OK)
  {
    Error_Handler();
  }
  if (HAL_ADCEx_Calibration_Start(&hadc2, ADC_DIFFERENTIAL_ENDED) != HAL_OK)
  {
    Error_Handler();
  }

  if (HAL_ADC_Start_DMA(&hadc2, (uint32_t *)g_adc2_dma_buf, 3) != HAL_OK)
  {
    Error_Handler();
  }
  __HAL_DMA_DISABLE_IT(&hdma_adc2, DMA_IT_TC | DMA_IT_HT);
  HAL_NVIC_ClearPendingIRQ(DMA1_Channel2_IRQn);
  HAL_NVIC_DisableIRQ(DMA1_Channel2_IRQn);

  if (HAL_ADC_Start_DMA(&hadc1, (uint32_t *)g_adc1_dma_buf, 2) != HAL_OK)
  {
    Error_Handler();
  }
  __HAL_DMA_DISABLE_IT(&hdma_adc1, DMA_IT_HT);

  if (HAL_TIM_Base_Start(&htim2) != HAL_OK)
  {
    Error_Handler();
  }
  if (HAL_TIM_PWM_Start(&htim2, TIM_CHANNEL_2) != HAL_OK)
  {
    Error_Handler();
  }


  /* USER CODE END 2 */

  /* USER CODE BEGIN RTOS_MUTEX */
  /* add mutexes, ... */
  /* USER CODE END RTOS_MUTEX */

  /* USER CODE BEGIN RTOS_SEMAPHORES */
  /* add semaphores, ... */
  /* USER CODE END RTOS_SEMAPHORES */

  /* USER CODE BEGIN RTOS_TIMERS */
  /* start timers, add new ones, ... */
  /* USER CODE END RTOS_TIMERS */

  /* USER CODE BEGIN RTOS_QUEUES */
  /* add queues, ... */
  /* USER CODE END RTOS_QUEUES */

  /* Create the thread(s) */
  /* definition and creation of defaultTask */
  osThreadStaticDef(defaultTask, StartDefaultTask, osPriorityNormal, 0, 128, defaultTaskBuffer, &defaultTaskControlBlock);
  defaultTaskHandle = osThreadCreate(osThread(defaultTask), NULL);

  /* definition and creation of usbCDCTxTask */
  osThreadStaticDef(usbCDCTxTask, StartUsbCDCTxTask, osPriorityNormal, 0, 256, usbCDCTxTaskBuffer, &usbCDCTxTaskControlBlock);
  usbCDCTxTaskHandle = osThreadCreate(osThread(usbCDCTxTask), NULL);

  /* definition and creation of telemetryTask */
  osThreadStaticDef(telemetryTask, StartTelemetryTask, osPriorityNormal, 0, 512, telemetryTaskBuffer, &telemetryTaskControlBlock);
  telemetryTaskHandle = osThreadCreate(osThread(telemetryTask), NULL);

  /* definition and creation of slowAdcTask */
  osThreadStaticDef(slowAdcTask, StartSlowAdcTask, osPriorityLow, 0, 128, myTask04Buffer, &myTask04ControlBlock);
  slowAdcTaskHandle = osThreadCreate(osThread(slowAdcTask), NULL);

  /* definition and creation of cliTask */
  osThreadStaticDef(cliTask, StartCliTask, osPriorityLow, 0, 2048, myTask05Buffer, &myTask05ControlBlock);
  cliTaskHandle = osThreadCreate(osThread(cliTask), NULL);

  /* definition and creation of uartParsingTask */
  osThreadStaticDef(uartParsingTask, StartUartParsingTask, osPriorityNormal, 0, 256, myTask06Buffer, &myTask06ControlBlock);
  uartParsingTaskHandle = osThreadCreate(osThread(uartParsingTask), NULL);

  /* USER CODE BEGIN RTOS_THREADS */
  AppWatchdog_RefreshBeforeScheduler();
  /* USER CODE END RTOS_THREADS */

  /* Start scheduler */
  osKernelStart();

  /* We should never get here as control is now taken by the scheduler */

  /* Infinite loop */
  /* USER CODE BEGIN WHILE */
  while (1)
  {
    /* USER CODE END WHILE */

    /* USER CODE BEGIN 3 */
  }
  /* USER CODE END 3 */
}

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
/* USER CODE BEGIN Header_StartDefaultTask */
/**
  * @brief  Function implementing the defaultTask thread.
  * @param  argument: Not used
  * @retval None
  */
/* USER CODE END Header_StartDefaultTask */
void StartDefaultTask(void const * argument)
{
  /* init code for USB_Device */
  MX_USB_Device_Init();
  /* USER CODE BEGIN 5 */
  AppWatchdog_SupervisorRun(argument);
  /* USER CODE END 5 */
}

/* USER CODE BEGIN Header_StartUsbCDCTxTask */
/**
* @brief Function implementing the usbCDCTxTask thread.
* @param argument: Not used
* @retval None
*/
/* USER CODE END Header_StartUsbCDCTxTask */
void StartUsbCDCTxTask(void const * argument)
{
  /* USER CODE BEGIN StartUsbCDCTxTask */
  DbgUsb_TxTask(argument);
  /* USER CODE END StartUsbCDCTxTask */
}

/* USER CODE BEGIN Header_StartTelemetryTask */
/**
* @brief Function implementing the telemetryTask thread.
* @param argument: Not used
* @retval None
*/
/* USER CODE END Header_StartTelemetryTask */
void StartTelemetryTask(void const * argument)
{
  /* USER CODE BEGIN StartTelemetryTask */
  /* Infinite loop */
  static uint32_t hello_seq = 0U;
  static uint32_t last_adc_rate_ms = 0U;
  static uint32_t last_adc_seq_count = 0U;
  static uint32_t adc_seq_hz = 0U;
  char msg[640];
  for(;;)
  {
    const uint32_t now_ms = HAL_GetTick();
    if (last_adc_rate_ms == 0U)
    {
      last_adc_rate_ms = now_ms;
      last_adc_seq_count = g_adc_seq_count;
    }
    else
    {
      const uint32_t dt_ms = (uint32_t)(now_ms - last_adc_rate_ms);
      if (dt_ms >= 1000U)
      {
        const uint32_t seq_count_now = g_adc_seq_count;
        const uint32_t dseq = (uint32_t)(seq_count_now - last_adc_seq_count);
        if (dt_ms != 0U)
        {
          adc_seq_hz = (uint32_t)((dseq * 1000U + (dt_ms / 2U)) / dt_ms);
        }
        last_adc_rate_ms = now_ms;
        last_adc_seq_count = seq_count_now;
      }
    }
    g_adc_seq_hz = adc_seq_hz;
    g_telemetry_seq = hello_seq;

    /* T1 is a diagnostic snapshot. Values are deliberately sampled from the
     * existing DMA/register/shared-state snapshots without changing control. */
    const uint16_t adc_vcap = g_adc1_dma_buf[0] & 0x0FFFu;
    const uint16_t adc_vbus = g_adc1_dma_buf[1] & 0x0FFFu;
    const uint16_t adc_iload = g_adc2_dma_buf[0] & 0x0FFFu;
    const uint16_t adc_iop = g_adc2_dma_buf[1] & 0x0FFFu;
    const uint16_t adc_ion = g_adc2_dma_buf[2] & 0x0FFFu;
    const float v_bus = g_latest.v_bus;
    const float v_cap = g_latest.v_cap;
    const float i_load = g_latest.i_load;
    const float i_out_p = g_latest.i_out_p;
    const float i_out_n = g_latest.i_out_n;
    const float i_out = g_latest.i_out;
    const float i_conv = g_latest.i_conv;
    const int32_t cap_energy_mj = g_cap_energy_mj;
    can_command_state_t can_command;
    uart_command_state_t uart_command;
    manual_command_state_t manual_command;
    pushbutton_command_state_t pushbutton_command;
    control_status_t control_status;
    capacitor_monitor_status_t cap_monitor_status;
    CanProtocol_ReadCommandSnapshot(&can_command);
    CommandInputs_ReadUartSnapshot(&uart_command);
    CommandInputs_ReadManualSnapshot(&manual_command);
    CommandInputs_ReadPushbuttonSnapshot(&pushbutton_command);
    ScapIo_ReadStatus(&control_status);
    CapacitorMonitor_ReadStatus(&cap_monitor_status);
    DbgUsbStats dbg_stats;
    DbgUsb_GetStats(&dbg_stats);
    const uint32_t can_tx_enqueue_failures = TelemetrySlowAdcTask_GetCanTxEnqueueFailureCount();

    const uint32_t can_valid = can_command.can_cmd_timestamp != 0u ? 1u : 0u;
    const uint32_t can_bus_up = CanProtocol_IsBusActive(now_ms) ? 1u : 0u;
    const uint32_t uart_swen_req = (control_status.uart_power_fresh &&
                                    control_status.uart_energy_fresh) ? 1u : 0u;
    const int32_t v_bus_mV = (int32_t)(v_bus * 1000.0f);
    const int32_t v_cap_mV = (int32_t)(v_cap * 1000.0f);
    const int32_t i_load_mA = (int32_t)(i_load * 1000.0f);
    const int32_t i_out_p_mA = (int32_t)(i_out_p * 1000.0f);
    const int32_t i_out_n_mA = (int32_t)(i_out_n * 1000.0f);
    const int32_t i_out_mA = (int32_t)(i_out * 1000.0f);
    const int32_t i_conv_mA = (int32_t)(i_conv * 1000.0f);
    const int32_t pset_w = (int32_t)g_latest.p_set;
    const int32_t vcap_max_mV = (int32_t)(cap_monitor_status.vcap_max_v * 1000.0f + 0.5f);
    const uint32_t swen_out = HAL_GPIO_ReadPin(GPIOB, GPIO_SWEN_Pin) != GPIO_PIN_RESET ? 1u : 0u;
    const uint32_t dir_out = HAL_GPIO_ReadPin(GPIOB, GPIO_DIR_Pin) != GPIO_PIN_RESET ? 1u : 0u;
    const uint32_t mode_out =
        (HAL_GPIO_ReadPin(GPIOB, GPIO_MODEMSB_Pin) != GPIO_PIN_RESET ? 2u : 0u) |
        (HAL_GPIO_ReadPin(GPIOB, GPIO_MODELSB_Pin) != GPIO_PIN_RESET ? 1u : 0u);
    const uint32_t rvsoff_out = HAL_GPIO_ReadPin(GPIOB, GPIO_RVSOFF_Pin) != GPIO_PIN_RESET ? 1u : 0u;
    const uint32_t nsil_out = HAL_GPIO_ReadPin(GPIOB, GPIO_NSIL_Pin) != GPIO_PIN_RESET ? 1u : 0u;
    const uint32_t led_out = HAL_GPIO_ReadPin(GPIO_LED_GPIO_Port, GPIO_LED_Pin) != GPIO_PIN_RESET ? 1u : 0u;
    const uint32_t btn_in = HAL_GPIO_ReadPin(GPIOC, GPIO_PIN_13) != GPIO_PIN_RESET ? 1u : 0u;
    const uint32_t dac1_ch1 = HAL_DAC_GetValue(&hdac1, DAC_CHANNEL_1) & 0x0FFFu;
    const uint32_t dac1_ch2 = HAL_DAC_GetValue(&hdac1, DAC_CHANNEL_2) & 0x0FFFu;
    const uint32_t dac3_ch1 = HAL_DAC_GetValue(&hdac3, DAC_CHANNEL_1) & 0x0FFFu;
    const uint32_t dac3_ch2 = HAL_DAC_GetValue(&hdac3, DAC_CHANNEL_2) & 0x0FFFu;
    int len = snprintf(msg,
                       sizeof(msg),
                       "T1,%lu,%lu,%lu,%lu,%lu,%u,%u,%u,%u,%u,%ld,%ld,%ld,%ld,%ld,%ld,%ld,%ld,%lu,%lu,%lu,%lu,%lu,%lu,%lu,%lu,%lu,%lu,%lu,%u,%u,%u,%u,%u,%u,%u,%u,%lu,%u,%u,%u,%u,%u,%u,%u,%u,%u,%u,%u,%u,%u,%u,%u,%u,%u,%d,%u,%u,%u,%u,%u,%ld,%ld,%u,%u,%u,%ld,%ld,%lu\r\n",
                       (unsigned long)hello_seq++,
                       (unsigned long)adc_seq_hz,
                       (unsigned long)dbg_stats.telemetry_records_dropped,
                       (unsigned long)g_dma1_ch1_irq_cycles_last,
                       (unsigned long)g_dma1_ch1_irq_cycles_max,
                       (unsigned)adc_vcap,
                       (unsigned)adc_vbus,
                       (unsigned)adc_iload,
                       (unsigned)adc_iop,
                       (unsigned)adc_ion,
                       (long)v_cap_mV,
                       (long)v_bus_mV,
                       (long)i_load_mA,
                       (long)i_out_p_mA,
                       (long)i_out_n_mA,
                       (long)i_out_mA,
                       (long)i_conv_mA,
                       (long)pset_w,
                       (unsigned long)btn_in,
                       (unsigned long)dir_out,
                       (unsigned long)swen_out,
                       (unsigned long)mode_out,
                       (unsigned long)rvsoff_out,
                       (unsigned long)nsil_out,
                       (unsigned long)led_out,
                       (unsigned long)dac1_ch1,
                       (unsigned long)dac1_ch2,
                       (unsigned long)dac3_ch1,
                       (unsigned long)dac3_ch2,
                       (unsigned)control_status.mode_request,
                       (unsigned)control_status.decision,
                       control_status.swen_request ? 1u : 0u,
                       g_is_safe ? 1u : 0u,
                       control_status.uvlo_lockout ? 1u : 0u,
                       control_status.fault_latched ? 1u : 0u,
                       (unsigned)control_status.fault_bits,
                       (unsigned)control_status.fault_healthy_ms,
                       (unsigned long)can_bus_up,
                       (unsigned)can_command.can_power,
                       (unsigned)can_valid,
                       control_status.can_fresh ? 1u : 0u,
                       (unsigned)can_command.can_energy,
                       (can_valid != 0u && !can_command.can_energy_disabled) ? 1u : 0u,
                       control_status.can_fresh ? 1u : 0u,
                       can_command.can_energy_disabled ? 1u : 0u,
                       can_command.can_swen ? 1u : 0u,
                       (unsigned)can_valid,
                       control_status.can_fresh ? 1u : 0u,
                       (unsigned)uart_command.power_w.value,
                       uart_command.power_w.present ? 1u : 0u,
                       control_status.uart_power_fresh ? 1u : 0u,
                       (unsigned)uart_command.energy_j.value,
                       uart_command.energy_j.present ? 1u : 0u,
                       control_status.uart_energy_fresh ? 1u : 0u,
                       (unsigned)uart_swen_req,
                       (int)manual_command.power_w.value,
                       manual_command.power_w.present ? 1u : 0u,
                       manual_command.swen.value ? 1u : 0u,
                       manual_command.swen.present ? 1u : 0u,
                       pushbutton_command.swen.value ? 1u : 0u,
                       pushbutton_command.swen.present ? 1u : 0u,
                       (long)cap_energy_mj,
                       (long)vcap_max_mV,
                       cap_monitor_status.unhealthy_latched ? 1u : 0u,
                       (unsigned)cap_monitor_status.bad_window_count,
                       (unsigned)cap_monitor_status.derate_count,
                       (long)cap_monitor_status.last_energy_gain_mj,
                       (long)cap_monitor_status.last_vcap_gain_mv,
                       (unsigned long)can_tx_enqueue_failures);
    if (len > 0)
    {
      size_t msg_len = (size_t)len;
      if (msg_len >= sizeof(msg))
      {
        msg[sizeof(msg) - 3U] = '\r';
        msg[sizeof(msg) - 2U] = '\n';
        msg[sizeof(msg) - 1U] = '\0';
        msg_len = sizeof(msg) - 1U;
      }
      (void)TelemetryUart_TryWrite((const uint8_t *)msg, (uint16_t)msg_len);
      if (g_usb_telemetry_enabled)
      {
        (void)dbg_try_write((const uint8_t *)msg, (uint16_t)msg_len);
      }
    }
    AppWatchdog_Heartbeat(APP_WATCHDOG_TASK_TELEMETRY);
    osDelay(10);
  }
  /* USER CODE END StartTelemetryTask */
}

/* USER CODE BEGIN Header_StartSlowAdcTask */
/**
* @brief Function implementing the slowAdcTask thread.
* @param argument: Not used
* @retval None
*/
/* USER CODE END Header_StartSlowAdcTask */
void StartSlowAdcTask(void const * argument)
{
  /* USER CODE BEGIN StartSlowAdcTask */
  TelemetrySlowAdcTask_Run(argument);

  for (;;)
  {
    osDelay(1000);
  }
  /* USER CODE END StartSlowAdcTask */
}

/* USER CODE BEGIN Header_StartCliTask */
/**
* @brief Function implementing the cliTask thread.
* @param argument: Not used
* @retval None
*/
/* USER CODE END Header_StartCliTask */
void StartCliTask(void const * argument)
{
  /* USER CODE BEGIN StartCliTask */
  UsbCli_Task(argument);
  /* USER CODE END StartCliTask */
}

/* USER CODE BEGIN Header_StartUartParsingTask */
/**
* @brief Function implementing the uartParsingTask thread.
* @param argument: Not used
* @retval None
*/
/* USER CODE END Header_StartUartParsingTask */
void StartUartParsingTask(void const * argument)
{
  /* USER CODE BEGIN StartUartParsingTask */
  (void)argument;
  RefereeUart_Task(&huart3);
  /* USER CODE END StartUartParsingTask */
}

/**
  * @brief  Period elapsed callback in non blocking mode
  * @note   This function is called  when TIM1 interrupt took place, inside
  * HAL_TIM_IRQHandler(). It makes a direct call to HAL_IncTick() to increment
  * a global variable "uwTick" used as application time base.
  * @param  htim : TIM handle
  * @retval None
  */
void HAL_TIM_PeriodElapsedCallback(TIM_HandleTypeDef *htim)
{
  if (htim->Instance == TIM1)
  {
    HAL_IncTick();
  }
}

/**
  * @brief  This function is executed in case of error occurrence.
  * @retval None
  */
void Error_Handler(void)
{
  /* USER CODE BEGIN Error_Handler_Debug */
  /* User can add his own implementation to report the HAL error return state */
  __disable_irq();
  while (1)
  {
  }
  /* USER CODE END Error_Handler_Debug */
}

#ifdef  USE_FULL_ASSERT
/**
  * @brief  Reports the name of the source file and the source line number
  *         where the assert_param error has occurred.
  * @param  file: pointer to the source file name
  * @param  line: assert_param error line source number
  * @retval None
  */
void assert_failed(uint8_t *file, uint32_t line)
{
  /* USER CODE BEGIN 6 */
  /* User can add his own implementation to report the file name and line number,
     ex: printf("Wrong parameters value: file %s on line %d\r\n", file, line) */
  /* USER CODE END 6 */
}
#endif /* USE_FULL_ASSERT */

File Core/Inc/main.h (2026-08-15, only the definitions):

#define ADC1_IN1_Vcap_Pin GPIO_PIN_0
#define ADC1_IN1_Vcap_GPIO_Port GPIOA
#define ADC1_IN2_Vbus_Pin GPIO_PIN_1
#define ADC1_IN2_Vbus_GPIO_Port GPIOA
#define OPA1_DAC3_1_FBout_Pin GPIO_PIN_2
#define OPA1_DAC3_1_FBout_GPIO_Port GPIOA
#define DAC1_1_IMONINP_Pin GPIO_PIN_4
#define DAC1_1_IMONINP_GPIO_Port GPIOA
#define DAC1_2_IMONINN_Pin GPIO_PIN_5
#define DAC1_2_IMONINN_GPIO_Port GPIOA
#define GPIO_DIR_Pin GPIO_PIN_1
#define GPIO_DIR_GPIO_Port GPIOB
#define OPA3_IMONON_Pin GPIO_PIN_13
#define OPA3_IMONON_GPIO_Port GPIOB
#define OPA2_IMONOP_Pin GPIO_PIN_14
#define OPA2_IMONOP_GPIO_Port GPIOB
#define GPIO_LED_Pin GPIO_PIN_10
#define GPIO_LED_GPIO_Port GPIOA
#define GPIO_RVSOFF_Pin GPIO_PIN_3
#define GPIO_RVSOFF_GPIO_Port GPIOB
#define GPIO_SWEN_Pin GPIO_PIN_4
#define GPIO_SWEN_GPIO_Port GPIOB
#define GPIO_MODEMSB_Pin GPIO_PIN_5
#define GPIO_MODEMSB_GPIO_Port GPIOB
#define GPIO_MODELSB_Pin GPIO_PIN_6
#define GPIO_MODELSB_GPIO_Port GPIOB
#define GPIO_NSIL_Pin GPIO_PIN_7
#define GPIO_NSIL_GPIO_Port GPIOB

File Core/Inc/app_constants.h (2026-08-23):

#ifndef APP_CONSTANTS_H
#define APP_CONSTANTS_H

#include <stdbool.h>
#include <stdint.h>

/*
 * Global calibration/constants.
 *
 * Values in the "calibration" section can be overridden at runtime and persisted
 * to flash via EEPROM emulation.
 */

extern const uint32_t VREF_MV;

// V_bus = A_VBUS * N_adc_vbus + B_VBUS
extern float A_VBUS;     // V/count
extern float B_VBUS;     // V

// I_load = A_ILOAD * N_adc_iload + B_ILOAD
extern float A_ILOAD;    // A/count
extern float B_ILOAD;    // A
extern float MIDPOINT;   // count

// I_conv = P_set * (1/A_VBUS * 1/(N + N_OFFSET)) - I_load
extern float A_VBUS_INV;
extern float N_OFFSET;

// Clamp applied to I_conv in the fast DMA ISR (absolute value, Amps).
#define I_CONV_CLAMP_ABS_A (10.0f)
#define I_CAP_CLAMP_ABS_A (15.0f)

/* Control-policy thresholds (compile-time only; not EEPROM calibration). */
#define SCAP_VBUS_OVP_V                 (30.0f)
#define SCAP_VCAP_OVP_V                 (30.0f)
#define SCAP_UVLO_ENTER_V               (10.0f)
#define SCAP_UVLO_EXIT_V                (11.0f)
#define SCAP_VCAP_MAX_V                 (26.3f)
#define SCAP_VCAP_LOW_RATIO             (0.20f)
#define SCAP_VCAP_HYSTERESIS_V          (0.1f)
#define SCAP_ENERGY_CHARGE_J            (50u)
#define SCAP_ENERGY_DISCHARGE_J         (20u)
#define SCAP_POWER_HYSTERESIS           (10.0f)
#define SCAP_MANUAL_DEFAULT_POWER_W     (50.0f)
#define SCAP_COMMAND_FRESH_TIMEOUT_MS   (300u)
#define SCAP_FAULT_RECOVERY_MS          (500u)
#define SCAP_SWEN_MIN_ON_MS             (50u)
#define SCAP_SWEN_MIN_OFF_MS            (1u)
#define SCAP_DIR_MIN_TRANSITION_INTERVAL_US  (200u)
#define SCAP_DIR_MIN_TRANSITION_ISR_CYCLES   (10u)
#define SCAP_ADC_ISR_INTERVAL_S              (1.0f / 50000.0f)
#define SCAP_ENERGY_ISR_BLOCK_SAMPLES        (50u)
#define SCAP_ENERGY_ESTIMATED_CAPACITANCE_F  (5.0f)
#define SCAP_ENERGY_ANCHOR_V                  (23.0f)
#define SCAP_ENERGY_ANCHOR_REARM_V            (22.9f)
#define SCAP_ENERGY_ANCHOR_VALUE_MJ \
  (0.5f * SCAP_ENERGY_ESTIMATED_CAPACITANCE_F * SCAP_ENERGY_ANCHOR_V * SCAP_ENERGY_ANCHOR_V * 1000.0f)
#define SCAP_CAP_HEALTH_WINDOW_MS             (60000u)
#define SCAP_CAP_HEALTH_VOLTAGE_AVG_MS        (10000u)
#define SCAP_CAP_HEALTH_MIN_ENERGY_GAIN_MJ    (500000L)
#define SCAP_CAP_HEALTH_MAX_VOLTAGE_GAIN_MV   (100L)
#define SCAP_CAP_HEALTH_BAD_WINDOWS           (3u)
#define SCAP_VCAP_DERATE_STEP_V                (0.1f)
#define SCAP_VCAP_DERATE_MIN_V                 (23.0f)

// DAC setting (real units -> counts)
// N_dac_p = A_INP + I_conv * B_INP
extern float A_INP;      // counts
extern float B_INP;      // counts/A

// N_dac_n = A_INN + I_conv * B_INN
extern float A_INN;      // counts
extern float B_INN;      // counts/A

// V_cap = A_VCAP * N_adc_vcap + B_VCAP
extern float A_VCAP;     // V/count
extern float B_VCAP;     // V

// i_out_p = A_OP * N_adc_op + B_OP
extern float A_OP;       // A/count
extern float B_OP;       // A

// i_out_n = A_ON * N_adc_on + B_ON
extern float A_ON;       // A/count
extern float B_ON;       // A

// DAC3 default startup values (12-bit, right-aligned).
// These are written once during init and then remain unchanged unless the CLI
// overrides them via `dac set 3 <1|2> <0..4095>`.
extern uint32_t DAC3_CH1_BOOT_U12;
extern uint32_t DAC3_CH2_BOOT_U12;

void AppConstants_RecalcDerived(void);
void AppConstants_ResetToDefaults(void);
void AppConstants_InitFromNvm(void);
bool AppConstants_LoadFromNvm(void);
bool AppConstants_SaveToNvm(void);

extern const uint32_t SCAP_STAT_RATE_HZ; // 10..1000

#endif /* APP_CONSTANTS_H */

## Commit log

2026-01-29 update ioc for dma,adc
2026-01-29 update ioc for dma
2026-01-30 dac,adc,opamp,comp demo
2026-02-05 Add reciprocal ADC lookup table
2026-02-05 added adc calcs
2026-02-06 interrupt signal chain works
2026-02-06 change PB1 dir pin to software control
2026-02-06 added software DIR pin control
2026-02-06 added auto-manual switch for ISR
2026-02-06 added string printing to fix help cmd
2026-02-08 config USART3 dma in ioc
2026-02-08 prioritized adc and config uart chain
2026-02-08 UART parsing OK
2026-02-09 added can filters
2026-02-09 enable fdcan interrupt
2026-02-11 cal load/save prototype
2026-02-11 power resolving
2026-02-12 fix backfeeding (no more ccm)
    [scap_io_owner.c]
2026-02-13 adc sampling fallback
2026-02-13 check adc freq
2026-02-13 enable button interrupt
2026-02-14 fixed things getting optimized out
    [main.c]
2026-02-15 Create Calibration Script.ipynb
2026-02-15 added controller board hardware design files
2026-02-15 added capacitor bank design files
2026-02-15 add STEP models for all banks and controllers
    [3D_pancake_bank.step]
2026-02-15 added all reference designs
    [1698A (A,B,C) cf.xls, 1698a.sch, Arduino_extension_connectors.SchDoc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]
2026-02-15 remove bulk
    [1698A (A,B,C) cf.xls, 1698a.sch, Arduino_extension_connectors.SchDoc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]
2026-08-15 disable switching clock sync and improve usbc printing
2026-08-15 init PA10 LED to off on boot
2026-08-16 fix related to busoff
    [main.c]
2026-08-17 refactor pb/manual/uart/can mailboxes
2026-08-17 allow CAN energy switch (777)
2026-08-20 config usart 1 for wireless stream
2026-08-20 finish wiring up USART 1 to telemetry
2026-08-20 add udp support for wireless telemetry
2026-08-21 set IWDG to hang until next next reset
    [main.c]
2026-08-23 cap voltage foldback test
2026-09-03 docs: explain chassis power buffering
2026-09-03 docs: add chassis load-step response

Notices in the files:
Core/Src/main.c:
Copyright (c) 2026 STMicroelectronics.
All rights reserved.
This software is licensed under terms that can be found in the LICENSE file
